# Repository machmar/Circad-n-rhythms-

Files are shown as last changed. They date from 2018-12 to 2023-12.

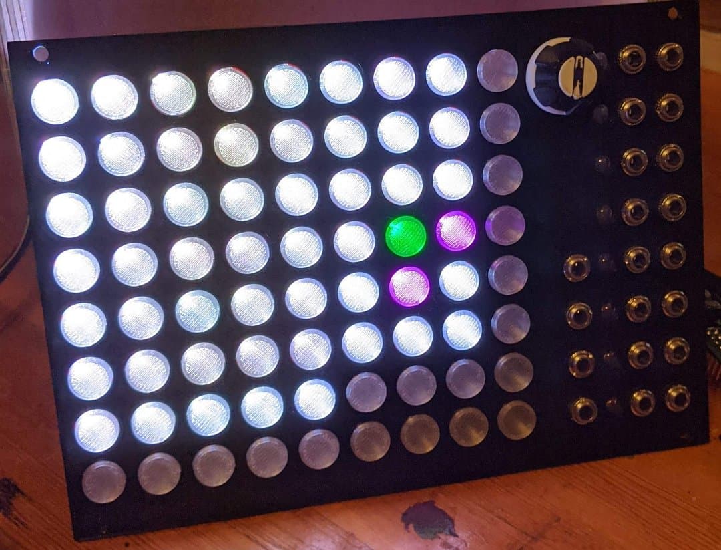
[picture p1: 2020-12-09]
wiki files/flashing/wrong speed.jpg

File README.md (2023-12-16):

# Circad-n-rhythms-

Sadly, this project has stalled and while I have plans to make it much better in the future, there so far is no date for these plans and other stuff is more important right now.    
  
If you are just seeing this module for the first time, let me introduce you to the basic concept of what it is and what it was.  
This is a eurorack module that was originally a clone of *Circadian Rhythms* by *TipTop Audio* but later on I decided to make it my own. I have rewritten the code and redisegined the PCB for it multiple times but never got into a place were the programming would get clean and straight forward. I suspect this is mostly because I coded the whole thing in one file with Arduino IDE. So if any new versions of the code ever come out, it willl be written in Microchip Studio instead.  But the Hardware, other than the noise on powerlines that it makes, is a in a good state with all the stuff nescessary for further development  
  
Anyways, all the mistakes that I am aware are now fixed and the module should be usable and responsive. the DAC is not used so it is not nescessary but if you want to you can have a go at adding the functionality, the protocol should be implemented with functions for intialization, selecting a channel and setting the voltage.

If you want to build it, or even build multiple and sell it to other people, send me an e-mail (marekmach24@gmail.com) and I'll send you the files for 3D printing like the faceplate, buttons and others (I'll also tell you what the serial number should be 🤭🤭). Advantage for doing it this way is that if you face any issues, I can help you out pretty quickly and easilly as you already have a direct line to me.  

More info here:  
Flashing guide [Here on wiki](https://github.com/machmar/Circad-n-rhythms-/wiki/)  
Video overview [on my youtube channel](https://youtu.be/im8Ey7QF54s)

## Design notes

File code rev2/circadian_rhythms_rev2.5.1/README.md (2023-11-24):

It has been a long time and I do not know what I changed in this update other then optimized ram consumption to just 55% instead of 95% which it was previously.  
  
Following is a copy of README.md from 2.5 folder:  
  
This update is different.
The right row of buttons now has a Shift button. The module has a builtin support - just hold any button down for like a seccond and it will tell you.

The list of function of the buttons:

```
[    sequence lenght    ]/[internal / external clock]
[ 64 steps of a channel ]/[-------------------------]
[8 steps of all channels]/[     clock multiplier    ]
[-----------------------]/[-------------------------]
[-----------------------]/[  gate / trigger output  ]
[      play / stop      ]/[-------------------------]
[         Shift         ]/[          Shift          ]
[-----------------------]/[       Save / Load       ]
```

The encoder changes the BPM when you have no menu open, othervise it changes some parameters from the menu.
Also to know what version of software you are on, hold the encoder down while you turn on the module. (the intro animation will play before it displays the version)
More features to come, Marek Mach.

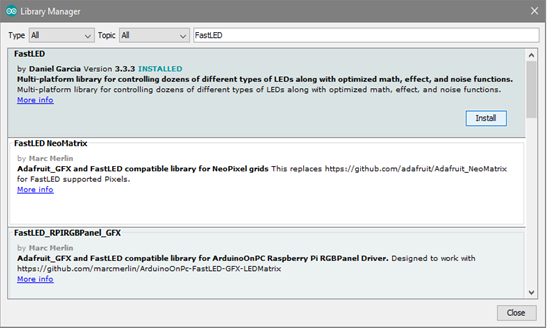
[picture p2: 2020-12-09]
wiki files/flashing/find lib.png

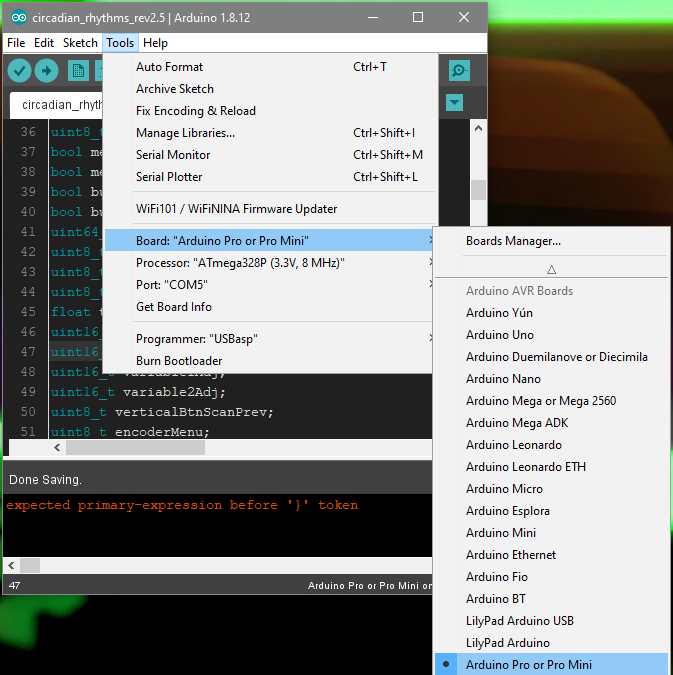
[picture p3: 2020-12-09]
wiki files/flashing/select board.png

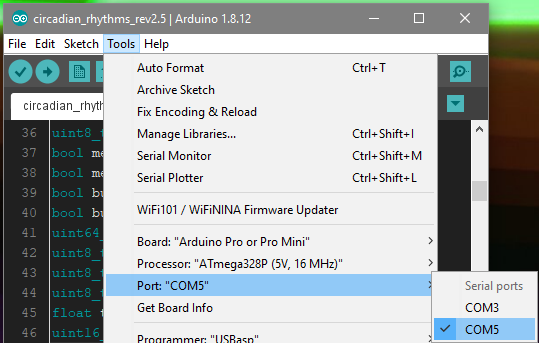
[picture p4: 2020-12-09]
wiki files/flashing/select port.png

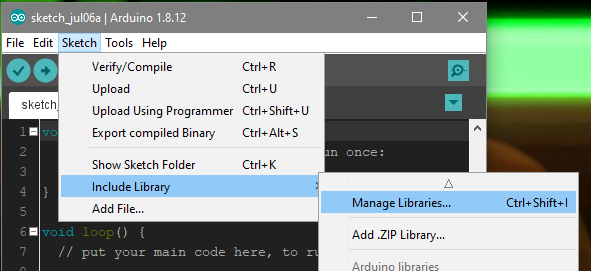
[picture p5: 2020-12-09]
wiki files/flashing/Include lib.png

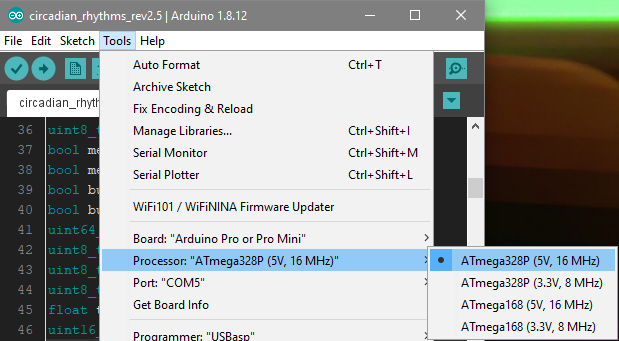
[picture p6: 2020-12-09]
wiki files/flashing/select speed.png

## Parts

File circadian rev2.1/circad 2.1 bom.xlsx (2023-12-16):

Circad rev2.1
Index | Qty | Description | Specs | Value | Package | References
SMT parts, top side
LED1 - LED72 | 72 | SK6812 3535 (chip inside must be facing side with no leads - up on the PCB) |  |  | 3535 | SK6812 3535 RGB LED (https://www.aliexpress.com/item/32623583544.html?spm=a2g0o.cart.0.0.69013c00TGmKdV&mp=1)
S1 - S72 | 72 | MOMENTARY-SWITCH-SMD-6.0X3.5MM | red |  | 6.0x3.5mm | MOMENTARY-SWITCH-SMD-6.0X3.5MM (https://vi.aliexpress.com/item/32914876022.html?spm=a2g0o.cart.0.0.69013c00TGmKdV&mp=1)
C13 - C22 | 10 | capacitor |  | 100n | 603
SMT parts, bottom side
R1, R2, R12 | 3 | resistor |  | 10k | 603
R3 - R11, R27 | 10 | resistor |  | 470 | 603
R13 - R16, R23 | 5 | resistor |  | 1k | 603
C24 | 1 | capacitor |  | 10uF | 603
C1 - C12, C23,C25, C26 | 14 | capacitor |  | 100n | 603
C27, C28 | 2 | capacitor |  | 470n | 603
D1, D2 | 2 | diode |  |  | SOD-123
F1, F2 | 2 | fuse |  | 2A | 1206
RXLED_GREEN | 1 | LED | green |  | 603
TXLED_BLUE | 1 | LED | blue |  | 603
X1 | 1 | USB B 2.0 |  |  |  | 806-KUSBX-SMTBS1NB30 (https://eu.mouser.com/ProductDetail/Kycon/KUSBX-SMT-BS1N-B30?qs=aTQdX%252BfNGTr9wUDDf73bMQ%3D%3D)
VAR_ADJ0, VAR_ADJ1, TEMP_ADJUST, BRIG_ADJUST | 4 | trimmer |  | 10k | 3x3 | Trimpot SMD 3X3 (https://www.aliexpress.com/item/33031044508.html?spm=a2g0o.cart.0.0.5f083c00TJpe2O&mp=1)
IC9 USE ONLY IC9 OR IC10, NOT BOTH! | 1 | zener diode | LM4040B10 | 10V | SOT-23
IC10 USE ONLY IC9 OR IC10, NOT BOTH! | 1 | zener diode | LM4040B05 | 5V | SOT-23
IC4, IC6 | 2 | shift register | 74HC595D |  | SO16
IC2, IC3, IC7 | 2 | multiplexer | 4051D |  | SO16
IC1 | 1 | decade counter | 4017D |  | SO16
IC5 | 1 | multiplexer | 4053D |  | SO16
IC8 | 1 | usb to serial converter | FT232RL |  | SSOP28
U$1 | 1 | temperature sensor | AD22100 |  | SO08
U$2 | 1 | digital analog converter | AD5328 |  | TSSOP16
U$5, U$6 | 2 | pwm voltage regulator | MINI-360 |  |  | Mini-360 Model Step-down Module (https://www.aliexpress.com/item/1631348154.html)
PTH parts, top side
LED73 - LED80 | 8 | 5mm LED | red |  | 5mm | generic 5mm red LED (https://www.aliexpress.com/item/33015212696.html)
CLOCK_IN, CLOCK_OUT, CV_OUT1 - CV_OUT8, TRIG/GATE_OUT1 - TRIG/GATE_OUT8, RESET_IN, RESET_OUT | 20 | Vertical stereo jack connector |  |  |  | PJ366ST (https://www.thonk.co.uk/shop/3-5mm-jacks/)
S73 | 1 | rotary encoder w/ button (D shaft) |  |  |  | 688-EC11E18244A5 (https://eu.mouser.com/ProductDetail/ALPS/EC11E18244A5)
PTH parts, bottom side
U$4 | 1 | 2x5, 2.54mm pitch male header
Arduino pro mini chinese clone | 1 | Arduino pro mini Atmega 328pu | 16MHz 5V |  |  | Arduino pro mini Atmega 328pu 16MHz 5V (https://www.aliexpress.com/item/32824418570.html)
PCB specifications
PCB |  | 173.97mm x 111.43mm ; 2 layers
 | 244

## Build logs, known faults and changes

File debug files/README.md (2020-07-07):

Here are alt firmwares for debugging hardware issues.

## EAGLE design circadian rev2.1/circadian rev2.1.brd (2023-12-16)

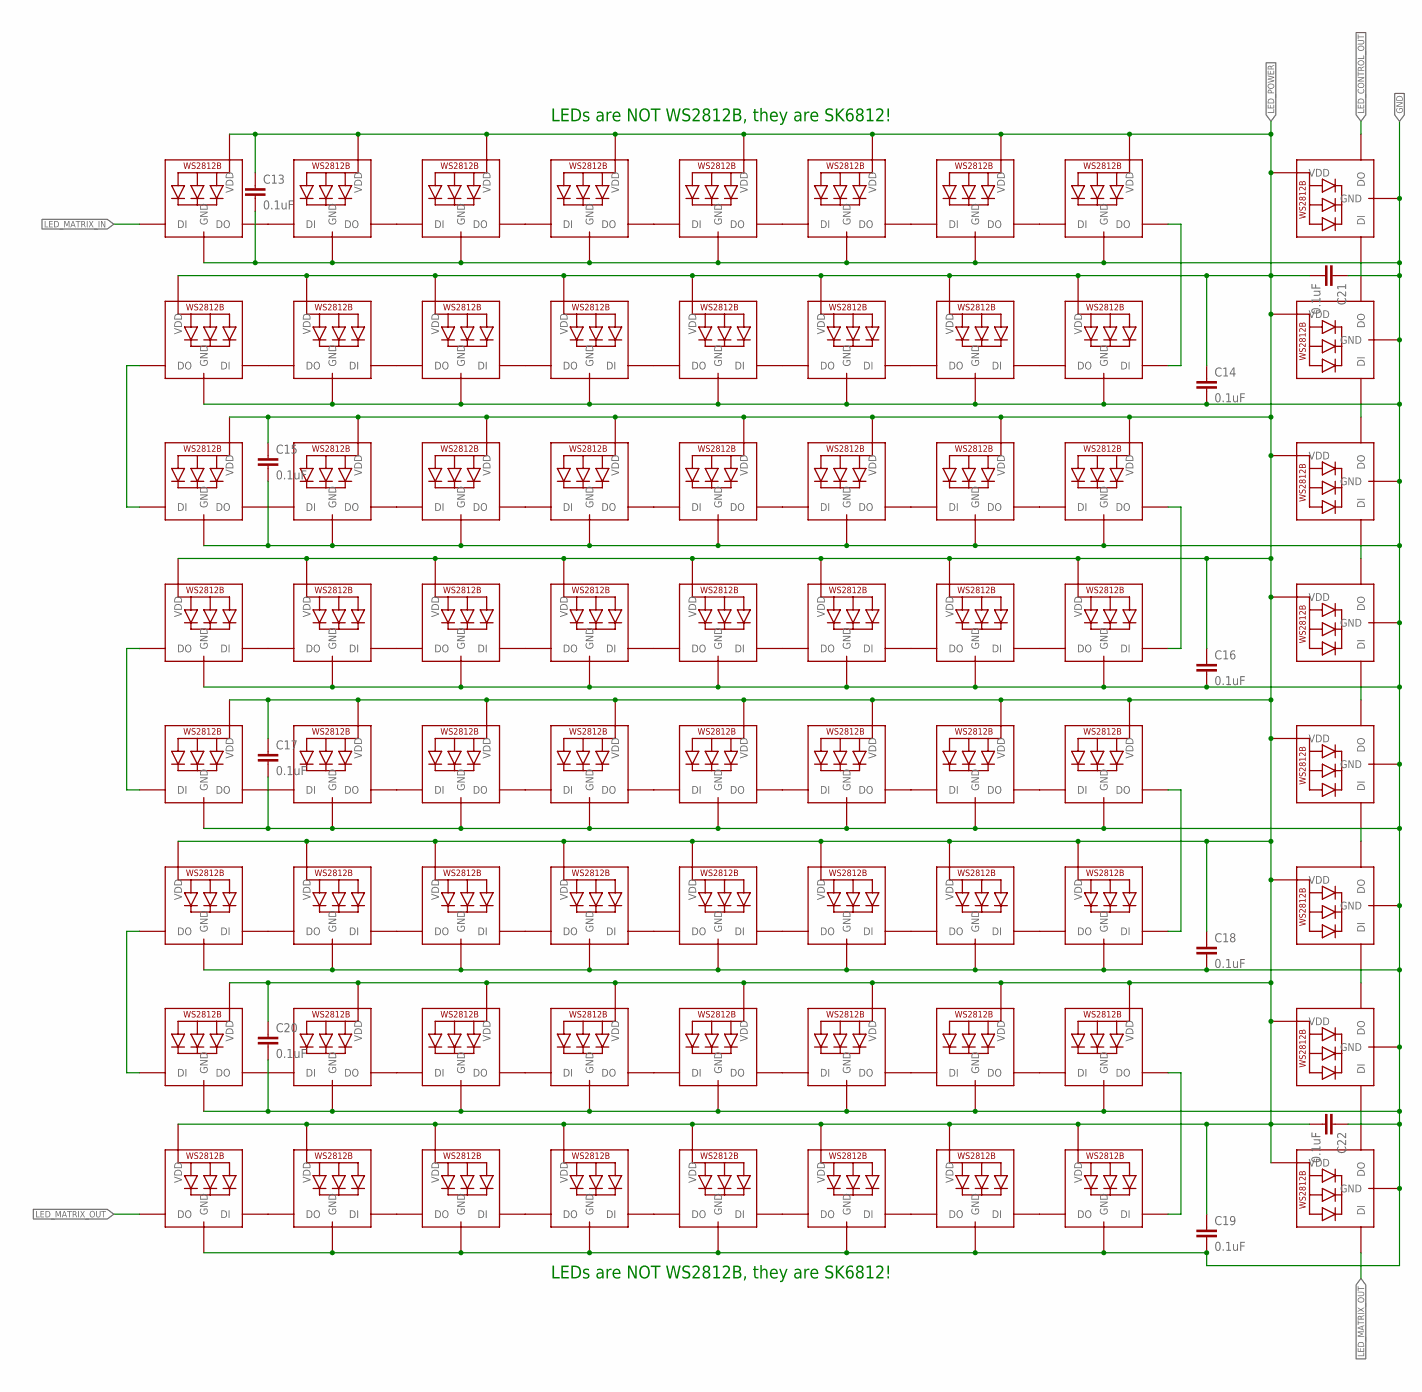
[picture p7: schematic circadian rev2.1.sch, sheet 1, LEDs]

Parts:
C13, C14, C15, C16, C17, C18, C19, C20, C21, C22: 0.1uF; 0603
LED1, LED2, LED3, LED4, LED5, LED6, LED7, LED8, LED9, LED10, LED11, LED12, LED13, LED14, LED15, LED16, LED17, LED18, LED19, LED20, LED21, LED22, LED23, LED24, LED25, LED26, LED27, LED28, LED29, LED30, LED31, LED32, LED33, LED34, LED35, LED36, LED37, LED38, LED39, LED40, LED41, LED42, LED43, LED44, LED45, LED46, LED47, LED48, LED49, LED50, LED51, LED52, LED53, LED54, LED55, LED56, LED57, LED58, LED59, LED60, LED61, LED62, LED63, LED64, LED65, LED66, LED67, LED68, LED69, LED70, LED71, LED72: SK68123535; LED3535

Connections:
GND: C13.2, C14.2, C15.2, C16.2, C17.2, C18.2, C19.2, C20.2, C21.1, C22.1, LED1.4 (GND), LED2.4 (GND), LED3.4 (GND), LED4.4 (GND), LED5.4 (GND), LED6.4 (GND), LED7.4 (GND), LED8.4 (GND), LED9.4 (GND), LED10.4 (GND), LED11.4 (GND), LED12.4 (GND), LED13.4 (GND), LED14.4 (GND), LED15.4 (GND), LED16.4 (GND), LED17.4 (GND), LED18.4 (GND), LED19.4 (GND), LED20.4 (GND), LED21.4 (GND), LED22.4 (GND), LED23.4 (GND), LED24.4 (GND), LED25.4 (GND), LED26.4 (GND), LED27.4 (GND), LED28.4 (GND), LED29.4 (GND), LED30.4 (GND), LED31.4 (GND), LED32.4 (GND), LED33.4 (GND), LED34.4 (GND), LED35.4 (GND), LED36.4 (GND), LED37.4 (GND), LED38.4 (GND), LED39.4 (GND), LED40.4 (GND), LED41.4 (GND), LED42.4 (GND), LED43.4 (GND), LED44.4 (GND), LED45.4 (GND), LED46.4 (GND), LED47.4 (GND), LED48.4 (GND), LED49.4 (GND), LED50.4 (GND), LED51.4 (GND), LED52.4 (GND), LED53.4 (GND), LED54.4 (GND), LED55.4 (GND), LED56.4 (GND), LED57.4 (GND), LED58.4 (GND), LED59.4 (GND), LED60.4 (GND), LED61.4 (GND), LED62.4 (GND), LED63.4 (GND), LED64.4 (GND), LED65.4 (GND), LED66.4 (GND), LED67.4 (GND), LED68.4 (GND), LED69.4 (GND), LED70.4 (GND), LED71.4 (GND), LED72.4 (GND); also elsewhere on the board
LED_CONTROL_OUT: LED65.3 (DO)
LED_MATRIX_IN: LED1.1 (DI); also elsewhere on the board
LED_MATRIX_OUT: LED64.3 (DO), LED72.1 (DI)
LED_POWER: C13.1, C14.1, C15.1, C16.1, C17.1, C18.1, C19.1, C20.1, C21.2, C22.2, LED1.2 (VDD), LED2.2 (VDD), LED3.2 (VDD), LED4.2 (VDD), LED5.2 (VDD), LED6.2 (VDD), LED7.2 (VDD), LED8.2 (VDD), LED9.2 (VDD), LED10.2 (VDD), LED11.2 (VDD), LED12.2 (VDD), LED13.2 (VDD), LED14.2 (VDD), LED15.2 (VDD), LED16.2 (VDD), LED17.2 (VDD), LED18.2 (VDD), LED19.2 (VDD), LED20.2 (VDD), LED21.2 (VDD), LED22.2 (VDD), LED23.2 (VDD), LED24.2 (VDD), LED25.2 (VDD), LED26.2 (VDD), LED27.2 (VDD), LED28.2 (VDD), LED29.2 (VDD), LED30.2 (VDD), LED31.2 (VDD), LED32.2 (VDD), LED33.2 (VDD), LED34.2 (VDD), LED35.2 (VDD), LED36.2 (VDD), LED37.2 (VDD), LED38.2 (VDD), LED39.2 (VDD), LED40.2 (VDD), LED41.2 (VDD), LED42.2 (VDD), LED43.2 (VDD), LED44.2 (VDD), LED45.2 (VDD), LED46.2 (VDD), LED47.2 (VDD), LED48.2 (VDD), LED49.2 (VDD), LED50.2 (VDD), LED51.2 (VDD), LED52.2 (VDD), LED53.2 (VDD), LED54.2 (VDD), LED55.2 (VDD), LED56.2 (VDD), LED57.2 (VDD), LED58.2 (VDD), LED59.2 (VDD), LED60.2 (VDD), LED61.2 (VDD), LED62.2 (VDD), LED63.2 (VDD), LED64.2 (VDD), LED65.2 (VDD), LED66.2 (VDD), LED67.2 (VDD), LED68.2 (VDD), LED69.2 (VDD), LED70.2 (VDD), LED71.2 (VDD), LED72.2 (VDD); also elsewhere on the board
unnamed: LED9.3 (DO), LED10.1 (DI)
unnamed: LED10.3 (DO), LED11.1 (DI)
unnamed: LED11.3 (DO), LED12.1 (DI)
unnamed: LED12.3 (DO), LED13.1 (DI)
unnamed: LED13.3 (DO), LED14.1 (DI)
unnamed: LED14.3 (DO), LED15.1 (DI)
unnamed: LED15.3 (DO), LED16.1 (DI)
unnamed: LED8.3 (DO), LED9.1 (DI)
unnamed: LED17.3 (DO), LED18.1 (DI)
unnamed: LED18.3 (DO), LED19.1 (DI)
unnamed: LED19.3 (DO), LED20.1 (DI)
unnamed: LED20.3 (DO), LED21.1 (DI)
unnamed: LED21.3 (DO), LED22.1 (DI)
unnamed: LED22.3 (DO), LED23.1 (DI)
unnamed: LED23.3 (DO), LED24.1 (DI)
unnamed: LED1.3 (DO), LED2.1 (DI)
unnamed: LED2.3 (DO), LED3.1 (DI)
unnamed: LED3.3 (DO), LED4.1 (DI)
unnamed: LED4.3 (DO), LED5.1 (DI)
unnamed: LED5.3 (DO), LED6.1 (DI)
unnamed: LED6.3 (DO), LED7.1 (DI)
unnamed: LED7.3 (DO), LED8.1 (DI)
unnamed: LED25.3 (DO), LED26.1 (DI)
unnamed: LED26.3 (DO), LED27.1 (DI)
unnamed: LED27.3 (DO), LED28.1 (DI)
unnamed: LED28.3 (DO), LED29.1 (DI)
unnamed: LED29.3 (DO), LED30.1 (DI)
unnamed: LED30.3 (DO), LED31.1 (DI)
unnamed: LED31.3 (DO), LED32.1 (DI)
unnamed: LED24.3 (DO), LED25.1 (DI)
unnamed: LED33.3 (DO), LED34.1 (DI)
unnamed: LED34.3 (DO), LED35.1 (DI)
unnamed: LED35.3 (DO), LED36.1 (DI)
unnamed: LED36.3 (DO), LED37.1 (DI)
unnamed: LED37.3 (DO), LED38.1 (DI)
unnamed: LED38.3 (DO), LED39.1 (DI)
unnamed: LED39.3 (DO), LED40.1 (DI)
unnamed: LED41.3 (DO), LED42.1 (DI)
unnamed: LED42.3 (DO), LED43.1 (DI)
unnamed: LED43.3 (DO), LED44.1 (DI)
unnamed: LED44.3 (DO), LED45.1 (DI)
unnamed: LED45.3 (DO), LED46.1 (DI)
unnamed: LED46.3 (DO), LED47.1 (DI)
unnamed: LED47.3 (DO), LED48.1 (DI)
unnamed: LED40.3 (DO), LED41.1 (DI)
unnamed: LED49.3 (DO), LED50.1 (DI)
unnamed: LED50.3 (DO), LED51.1 (DI)
unnamed: LED51.3 (DO), LED52.1 (DI)
unnamed: LED52.3 (DO), LED53.1 (DI)
unnamed: LED53.3 (DO), LED54.1 (DI)
unnamed: LED54.3 (DO), LED55.1 (DI)
unnamed: LED55.3 (DO), LED56.1 (DI)
unnamed: LED57.3 (DO), LED58.1 (DI)
unnamed: LED58.3 (DO), LED59.1 (DI)
unnamed: LED59.3 (DO), LED60.1 (DI)
unnamed: LED60.3 (DO), LED61.1 (DI)
unnamed: LED61.3 (DO), LED62.1 (DI)
unnamed: LED62.3 (DO), LED63.1 (DI)
unnamed: LED63.3 (DO), LED64.1 (DI)
unnamed: LED56.3 (DO), LED57.1 (DI)
unnamed: LED16.3 (DO), LED17.1 (DI)
unnamed: LED32.3 (DO), LED33.1 (DI)
unnamed: LED48.3 (DO), LED49.1 (DI)
unnamed: LED66.1 (DI), LED67.3 (DO)
unnamed: LED67.1 (DI), LED68.3 (DO)
unnamed: LED68.1 (DI), LED69.3 (DO)
unnamed: LED69.1 (DI), LED70.3 (DO)
unnamed: LED70.1 (DI), LED71.3 (DO)
unnamed: LED71.1 (DI), LED72.3 (DO)
unnamed: LED65.1 (DI), LED66.3 (DO)

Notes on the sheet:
LEDs are NOT WS2812B, they are SK6812!

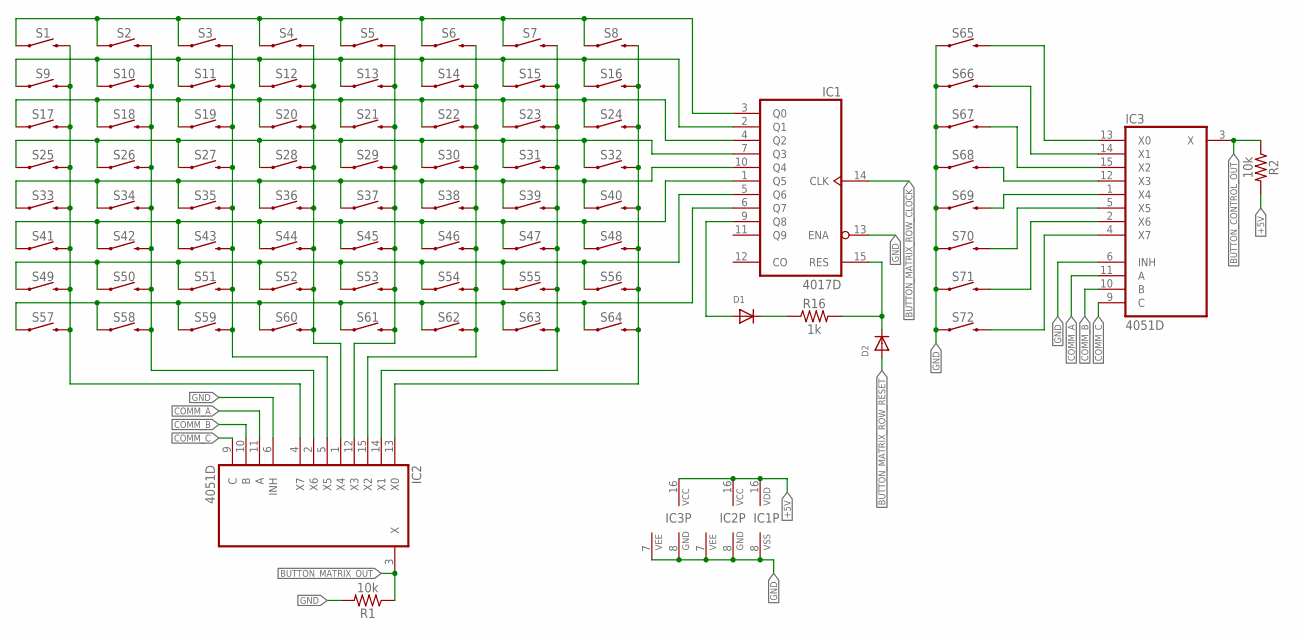
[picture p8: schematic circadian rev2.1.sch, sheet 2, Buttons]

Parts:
D1, D2: DIODESOD-123; SOD-123
IC1: 4017D; SO16
IC2, IC3: 4051D; SO16
R1, R2: 10k; 0603
R16: 1k; 0603
S1, S2, S3, S4, S5, S6, S7, S8, S9, S10, S11, S12, S13, S14, S15, S16, S17, S18, S19, S20, S21, S22, S23, S24, S25, S26, S27, S28, S29, S30, S31, S32, S33, S34, S35, S36, S37, S38, S39, S40, S41, S42, S43, S44, S45, S46, S47, S48, S49, S50, S51, S52, S53, S54, S55, S56, S57, S58, S59, S60, S61, S62, S63, S64, S65, S66, S67, S68, S69, S70, S71, S72: MOMENTARY-SWITCH-SPST-SMD-6.0X3.5MM; TACTILE_SWITCH_SMD_6.0X3.5MM

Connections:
+5V: IC1.16 (VDD), IC2.16 (VCC), IC3.16 (VCC), R2.2; also elsewhere on the board
BUTTON_CONTROL_OUT: IC3.3 (X), R2.1; also elsewhere on the board
BUTTON_MATRIX_COLLUM1: IC2.4 (X7), S1.2, S9.2, S17.2, S25.2, S33.2, S41.2, S49.2, S57.2
BUTTON_MATRIX_COLLUM2: IC2.2 (X6), S2.2, S10.2, S18.2, S26.2, S34.2, S42.2, S50.2, S58.2
BUTTON_MATRIX_COLLUM3: IC2.5 (X5), S3.2, S11.2, S19.2, S27.2, S35.2, S43.2, S51.2, S59.2
BUTTON_MATRIX_COLLUM4: IC2.1 (X4), S4.2, S12.2, S20.2, S28.2, S36.2, S44.2, S52.2, S60.2
BUTTON_MATRIX_COLLUM5: IC2.12 (X3), S5.2, S13.2, S21.2, S29.2, S37.2, S45.2, S53.2, S61.2
BUTTON_MATRIX_COLLUM6: IC2.15 (X2), S6.2, S14.2, S22.2, S30.2, S38.2, S46.2, S54.2, S62.2
BUTTON_MATRIX_COLLUM7: IC2.14 (X1), S7.2, S15.2, S23.2, S31.2, S39.2, S47.2, S55.2, S63.2
BUTTON_MATRIX_COLLUM8: IC2.13 (X0), S8.2, S16.2, S24.2, S32.2, S40.2, S48.2, S56.2, S64.2
BUTTON_MATRIX_OUT: IC2.3 (X), R1.1; also elsewhere on the board
BUTTON_MATRIX_ROW1: IC1.3 (Q0), S1.1, S2.1, S3.1, S4.1, S5.1, S6.1, S7.1, S8.1
BUTTON_MATRIX_ROW2: IC1.2 (Q1), S9.1, S10.1, S11.1, S12.1, S13.1, S14.1, S15.1, S16.1
BUTTON_MATRIX_ROW3: IC1.4 (Q2), S17.1, S18.1, S19.1, S20.1, S21.1, S22.1, S23.1, S24.1
BUTTON_MATRIX_ROW4: IC1.7 (Q3), S25.1, S26.1, S27.1, S28.1, S29.1, S30.1, S31.1, S32.1
BUTTON_MATRIX_ROW5: IC1.10 (Q4), S33.1, S34.1, S35.1, S36.1, S37.1, S38.1, S39.1, S40.1
BUTTON_MATRIX_ROW6: IC1.1 (Q5), S41.1, S42.1, S43.1, S44.1, S45.1, S46.1, S47.1, S48.1
BUTTON_MATRIX_ROW7: IC1.5 (Q6), S49.1, S50.1, S51.1, S52.1, S53.1, S54.1, S55.1, S56.1
BUTTON_MATRIX_ROW8: IC1.6 (Q7), S57.1, S58.1, S59.1, S60.1, S61.1, S62.1, S63.1, S64.1
BUTTON_MATRIX_ROW_CLOCK: IC1.14 (CLK); also elsewhere on the board
BUTTON_MATRIX_ROW_RESET: D2.A; also elsewhere on the board
COMM_A: IC2.11 (A), IC3.11 (A); also elsewhere on the board
COMM_B: IC2.10 (B), IC3.10 (B); also elsewhere on the board
COMM_C: IC2.9 (C), IC3.9 (C); also elsewhere on the board
GND: IC1.8 (VSS), IC1.13 (ENA), IC2.6 (INH), IC2.7 (VEE), IC2.8 (GND), IC3.6 (INH), IC3.7 (VEE), IC3.8 (GND), R1.2, S65.1, S66.1, S67.1, S68.1, S69.1, S70.1, S71.1, S72.1; also elsewhere on the board
unnamed: IC3.12 (X3), S68.2
unnamed: IC3.1 (X4), S69.2
unnamed: IC3.5 (X5), S70.2
unnamed: IC3.15 (X2), S67.2
unnamed: IC3.14 (X1), S66.2
unnamed: IC3.13 (X0), S65.2
unnamed: IC3.2 (X6), S71.2
unnamed: IC3.4 (X7), S72.2
unnamed: D1.C, R16.1
unnamed: D1.A, IC1.9 (Q8)
unnamed: D2.C, IC1.15 (RES), R16.2

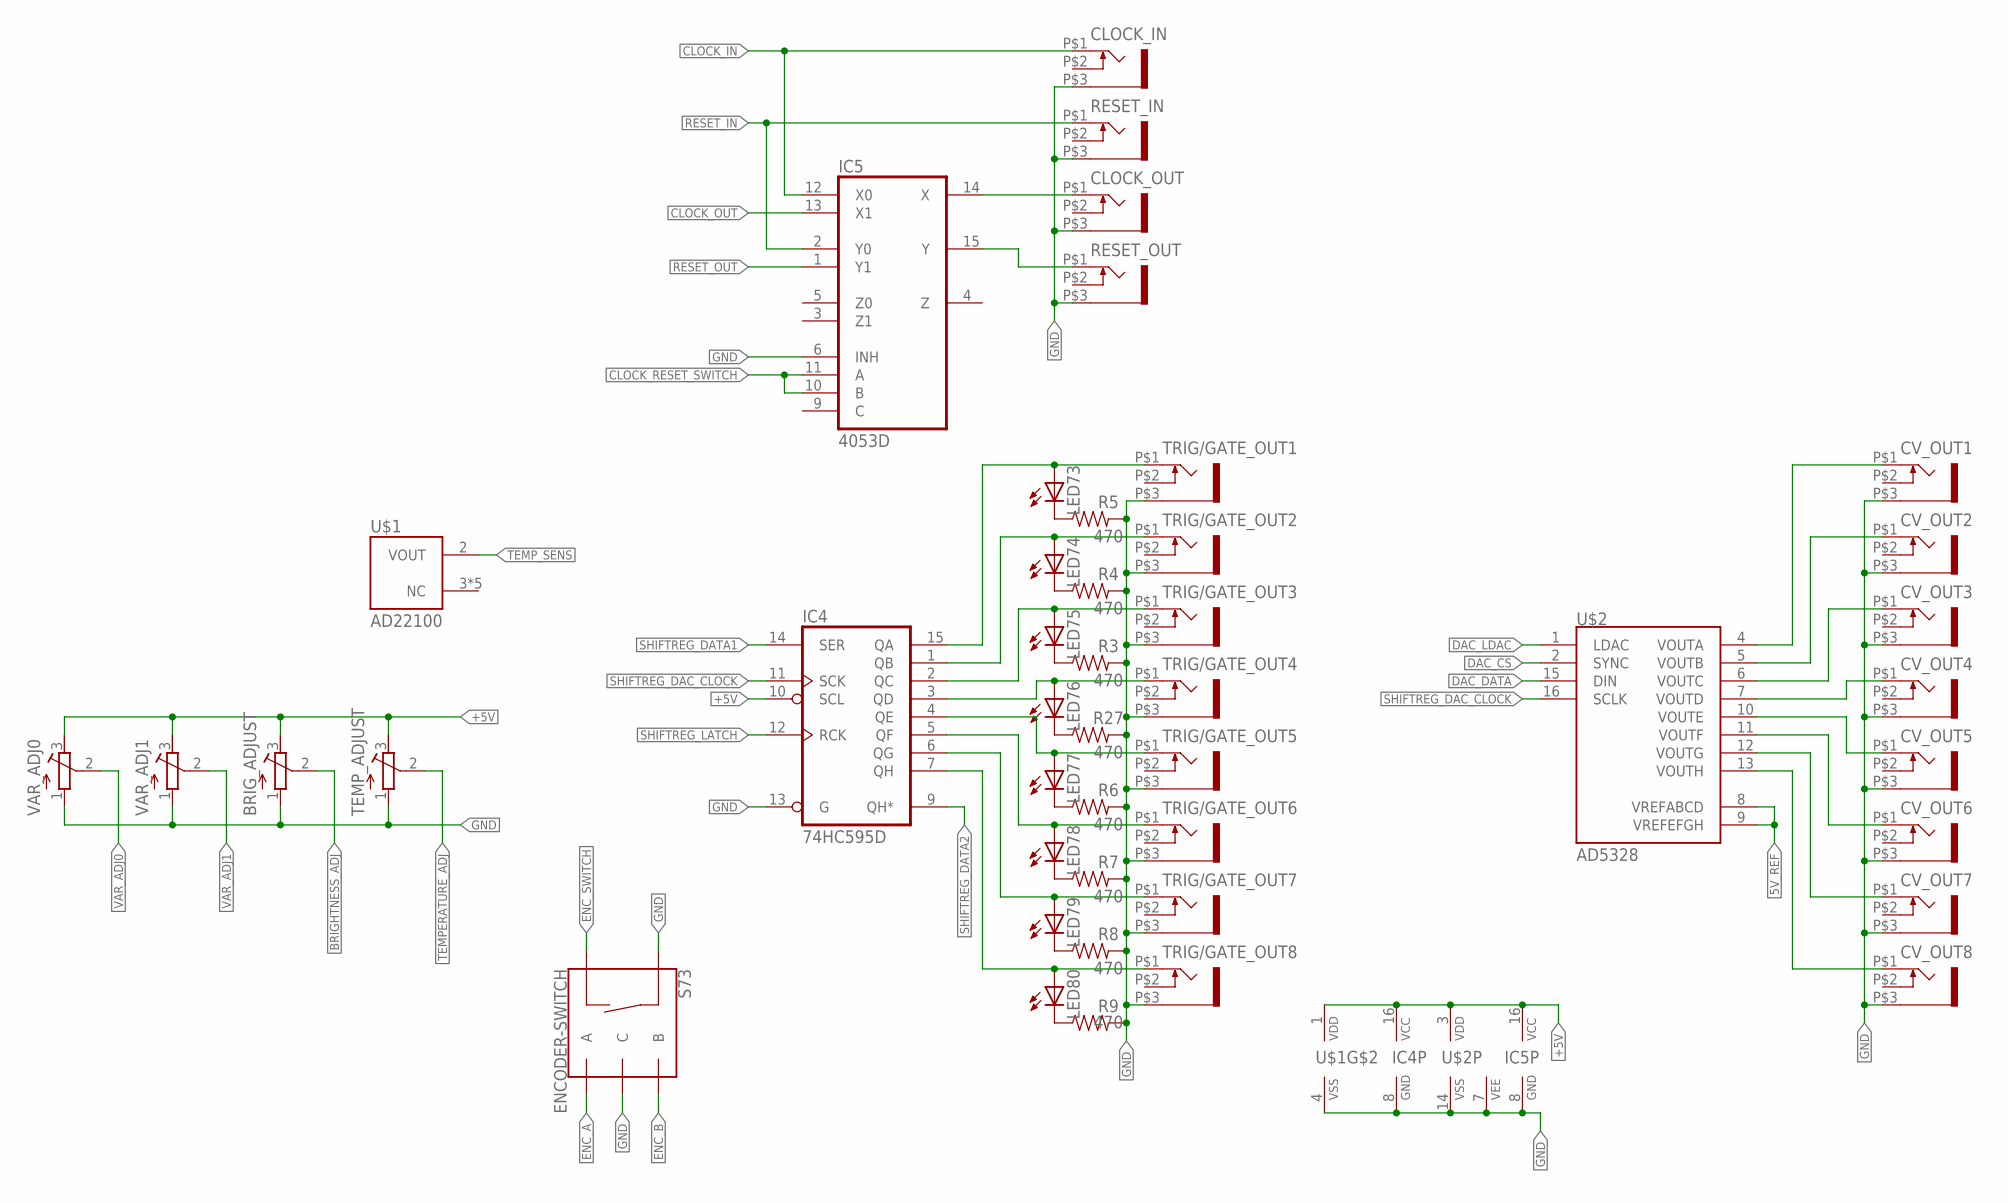
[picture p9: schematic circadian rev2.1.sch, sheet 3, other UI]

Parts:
BRIG_ADJUST: R-TRIMM4G/J; RTRIM4G/J
CLOCK_IN: WQP-PJ301M-12_JACK
CLOCK_OUT: WQP-PJ301M-12_JACK
CV_OUT1, CV_OUT2, CV_OUT3, CV_OUT4, CV_OUT5, CV_OUT6, CV_OUT7, CV_OUT8: WQP-PJ301M-12_JACK
IC4: 74HC595D; SO16
IC5: 4053D; SO16
LED73, LED74, LED75, LED76, LED77, LED78, LED79, LED80: LED5MM
R3, R4, R5, R6, R7, R8, R9, R27: 470; 0603
RESET_IN: WQP-PJ301M-12_JACK
RESET_OUT: WQP-PJ301M-12_JACK
S73: ENCODER-SWITCH; ROTARY_ENC_PLAIN
TEMP_ADJUST: R-TRIMM4G/J; RTRIM4G/J
TRIG/GATE_OUT1, TRIG/GATE_OUT2, TRIG/GATE_OUT3, TRIG/GATE_OUT4, TRIG/GATE_OUT5, TRIG/GATE_OUT6, TRIG/GATE_OUT7, TRIG/GATE_OUT8: WQP-PJ301M-12_JACK
U$1: AD22100; SO08
U$2: AD5328; TSSOP-16
VAR_ADJ0, VAR_ADJ1: R-TRIMM4G/J; RTRIM4G/J

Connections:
5V_REF: U$2.8 (VREFABCD), U$2.9 (VREFEFGH); also elsewhere on the board
+5V: BRIG_ADJUST.3 (E), IC4.10 (SCL), IC4.16 (VCC), IC5.16 (VCC), TEMP_ADJUST.3 (E), U$1.1 (VDD), U$2.3 (VDD), VAR_ADJ0.3 (E), VAR_ADJ1.3 (E); also elsewhere on the board
BRIGHTNESS_ADJ: BRIG_ADJUST.2 (S); also elsewhere on the board
CLOCK_IN: CLOCK_IN.P$1 (2), IC5.12 (X0); also elsewhere on the board
CLOCK_OUT: IC5.13 (X1); also elsewhere on the board
CLOCK_RESET_SWITCH: IC5.10 (B), IC5.11 (A); also elsewhere on the board
DAC_CS: U$2.2 (SYNC); also elsewhere on the board
DAC_DATA: U$2.15 (DIN); also elsewhere on the board
DAC_LDAC: U$2.1 (LDAC); also elsewhere on the board
ENC_A: S73.A; also elsewhere on the board
ENC_B: S73.B; also elsewhere on the board
ENC_SWITCH: S73.SW-; also elsewhere on the board
GND: BRIG_ADJUST.1 (A), CLOCK_IN.P$3 (1), CLOCK_OUT.P$3 (1), CV_OUT1.P$3 (1), CV_OUT2.P$3 (1), CV_OUT3.P$3 (1), CV_OUT4.P$3 (1), CV_OUT5.P$3 (1), CV_OUT6.P$3 (1), CV_OUT7.P$3 (1), CV_OUT8.P$3 (1), IC4.8 (GND), IC4.13 (G), IC5.6 (INH), IC5.7 (VEE), IC5.8 (GND), R3.2, R4.2, R5.2, R6.2, R7.2, R8.2, R9.2, R27.2, RESET_IN.P$3 (1), RESET_OUT.P$3 (1), S73.C, S73.SW+, TEMP_ADJUST.1 (A), TRIG/GATE_OUT1.P$3 (1), TRIG/GATE_OUT2.P$3 (1), TRIG/GATE_OUT3.P$3 (1), TRIG/GATE_OUT4.P$3 (1), TRIG/GATE_OUT5.P$3 (1), TRIG/GATE_OUT6.P$3 (1), TRIG/GATE_OUT7.P$3 (1), TRIG/GATE_OUT8.P$3 (1), U$1.4 (VSS), U$2.14 (VSS), VAR_ADJ0.1 (A), VAR_ADJ1.1 (A); also elsewhere on the board
unnamed: IC4.4 (QE), LED77.A, TRIG/GATE_OUT5.P$1 (2)
unnamed: IC4.3 (QD), LED76.A, TRIG/GATE_OUT4.P$1 (2)
unnamed: IC4.5 (QF), LED78.A, TRIG/GATE_OUT6.P$1 (2)
unnamed: IC4.6 (QG), LED79.A, TRIG/GATE_OUT7.P$1 (2)
unnamed: IC4.7 (QH), LED80.A, TRIG/GATE_OUT8.P$1 (2)
unnamed: IC4.2 (QC), LED75.A, TRIG/GATE_OUT3.P$1 (2)
unnamed: IC4.1 (QB), LED74.A, TRIG/GATE_OUT2.P$1 (2)
unnamed: IC4.15 (QA), LED73.A, TRIG/GATE_OUT1.P$1 (2)
unnamed: CV_OUT4.P$1 (2), U$2.7 (VOUTD)
unnamed: CV_OUT5.P$1 (2), U$2.10 (VOUTE)
unnamed: CV_OUT6.P$1 (2), U$2.11 (VOUTF)
unnamed: CV_OUT7.P$1 (2), U$2.12 (VOUTG)
unnamed: CV_OUT8.P$1 (2), U$2.13 (VOUTH)
unnamed: CV_OUT3.P$1 (2), U$2.6 (VOUTC)
unnamed: CV_OUT2.P$1 (2), U$2.5 (VOUTB)
unnamed: CV_OUT1.P$1 (2), U$2.4 (VOUTA)
unnamed: CLOCK_OUT.P$1 (2), IC5.14 (X)
unnamed: IC5.15 (Y), RESET_OUT.P$1 (2)
unnamed: LED76.K (C), R27.1
unnamed: LED75.K (C), R3.1
unnamed: LED74.K (C), R4.1
unnamed: LED73.K (C), R5.1
unnamed: LED77.K (C), R6.1
unnamed: LED78.K (C), R7.1
unnamed: LED79.K (C), R8.1
unnamed: LED80.K (C), R9.1
RESET_IN: IC5.2 (Y0), RESET_IN.P$1 (2); also elsewhere on the board
RESET_OUT: IC5.1 (Y1); also elsewhere on the board
SHIFTREG_DAC_CLOCK: IC4.11 (SCK), U$2.16 (SCLK); also elsewhere on the board
SHIFTREG_DATA1: IC4.14 (SER); also elsewhere on the board
SHIFTREG_DATA2: IC4.9 (QH*)
SHIFTREG_LATCH: IC4.12 (RCK); also elsewhere on the board
TEMPERATURE_ADJ: TEMP_ADJUST.2 (S); also elsewhere on the board
TEMP_SENS: U$1.2 (VOUT); also elsewhere on the board
VAR_ADJ0: VAR_ADJ0.2 (S); also elsewhere on the board
VAR_ADJ1: VAR_ADJ1.2 (S); also elsewhere on the board

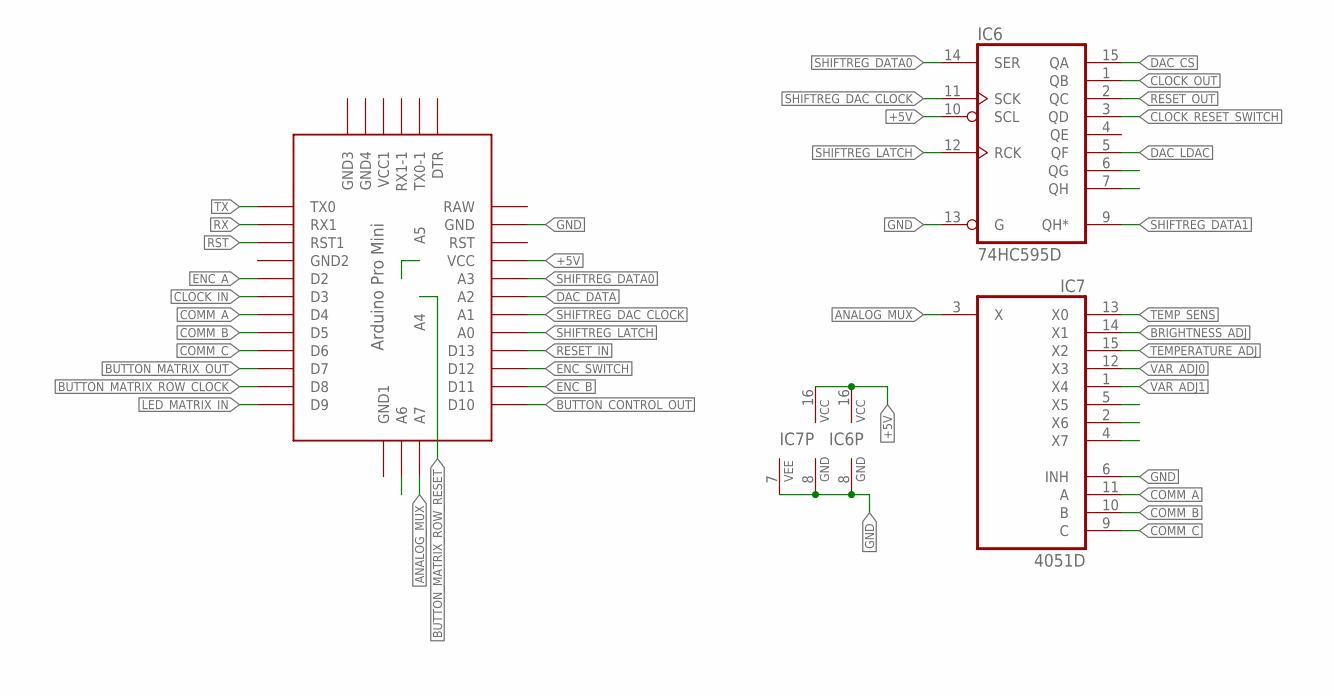
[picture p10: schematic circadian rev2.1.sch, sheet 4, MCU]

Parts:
IC6: 74HC595D; SO16
IC7: 4051D; SO16
U$3: ABK-PRO-MINI

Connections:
+5V: IC6.10 (SCL), IC6.16 (VCC), IC7.16 (VCC), U$3.VCC; also elsewhere on the board
ANALOG_MUX: IC7.3 (X), U$3.A7
BRIGHTNESS_ADJ: IC7.14 (X1); also elsewhere on the board
BUTTON_CONTROL_OUT: U$3.D10; also elsewhere on the board
BUTTON_MATRIX_OUT: U$3.D7; also elsewhere on the board
BUTTON_MATRIX_ROW_CLOCK: U$3.D8; also elsewhere on the board
BUTTON_MATRIX_ROW_RESET: U$3.A4; also elsewhere on the board
CLOCK_IN: U$3.D3; also elsewhere on the board
CLOCK_OUT: IC6.1 (QB); also elsewhere on the board
CLOCK_RESET_SWITCH: IC6.3 (QD); also elsewhere on the board
COMM_A: IC7.11 (A), U$3.D4; also elsewhere on the board
COMM_B: IC7.10 (B), U$3.D5; also elsewhere on the board
COMM_C: IC7.9 (C), U$3.D6; also elsewhere on the board
DAC_CS: IC6.15 (QA); also elsewhere on the board
DAC_DATA: U$3.A2; also elsewhere on the board
DAC_LDAC: IC6.5 (QF); also elsewhere on the board
ENC_A: U$3.D2; also elsewhere on the board
ENC_B: U$3.D11; also elsewhere on the board
ENC_SWITCH: U$3.D12; also elsewhere on the board
GND: IC6.8 (GND), IC6.13 (G), IC7.6 (INH), IC7.7 (VEE), IC7.8 (GND), U$3.GND; also elsewhere on the board
LED_MATRIX_IN: U$3.D9; also elsewhere on the board
RESET_IN: U$3.D13; also elsewhere on the board
RESET_OUT: IC6.2 (QC); also elsewhere on the board
RST: U$3.RST1; also elsewhere on the board
RX: U$3.RX1; also elsewhere on the board
SHIFTREG_DAC_CLOCK: IC6.11 (SCK), U$3.A1; also elsewhere on the board
SHIFTREG_DATA0: IC6.14 (SER), U$3.A3
SHIFTREG_DATA1: IC6.9 (QH*); also elsewhere on the board
SHIFTREG_LATCH: IC6.12 (RCK), U$3.A0; also elsewhere on the board
TEMPERATURE_ADJ: IC7.15 (X2); also elsewhere on the board
TEMP_SENS: IC7.13 (X0); also elsewhere on the board
TX: U$3.TX0; also elsewhere on the board
VAR_ADJ0: IC7.12 (X3); also elsewhere on the board
VAR_ADJ1: IC7.1 (X4); also elsewhere on the board

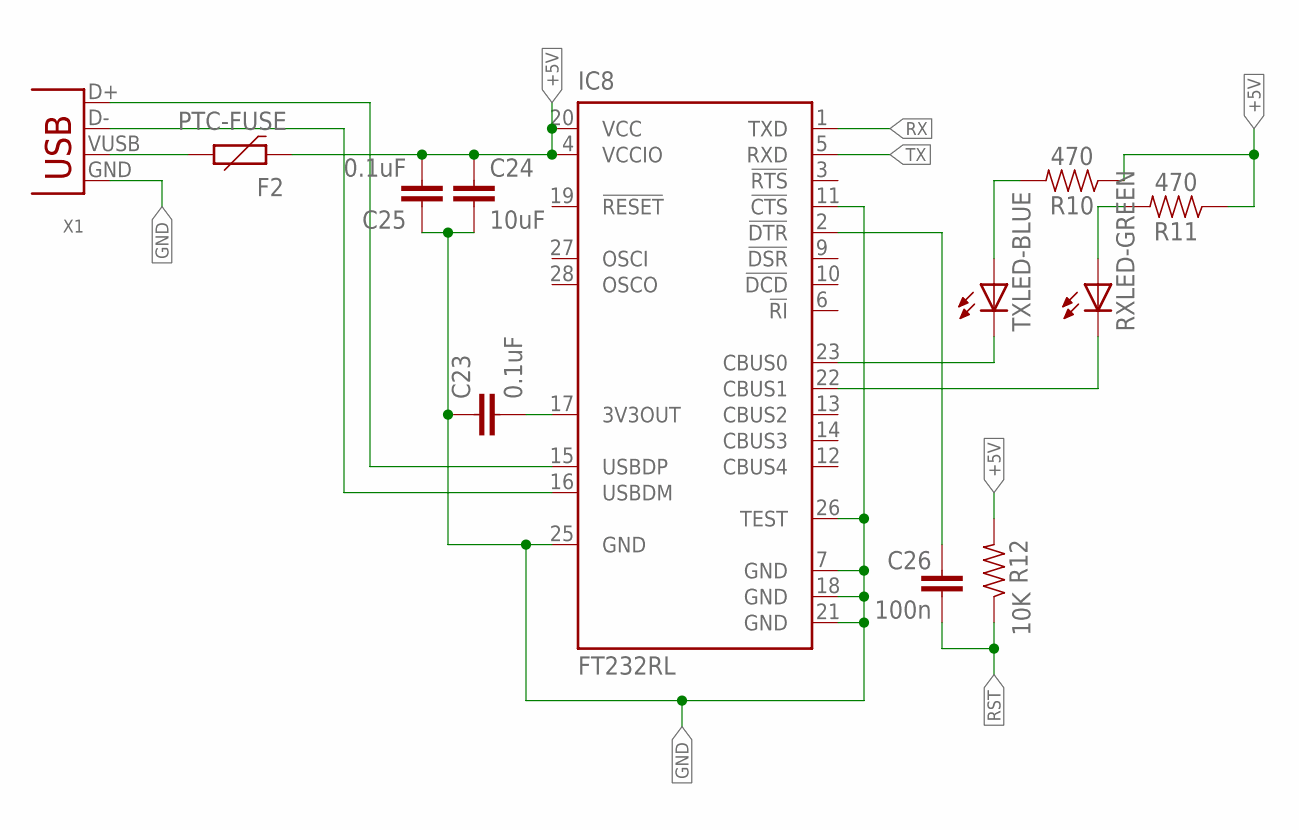
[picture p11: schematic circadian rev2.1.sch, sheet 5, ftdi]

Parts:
C23, C25: 0.1uF; 0603
C24: 10uF; 0603
C26: 100n; 0603-CAP
F2: PTC-FUSE; 1206
IC8: FT232RL; SSOP28
R10, R11: 470; 0603
R12: 10K; 0603-RES
RXLED-GREEN: LEDCHIP-LED0603; CHIP-LED0603
TXLED-BLUE: LEDCHIP-LED0603; CHIP-LED0603
X1: USB-B-S; USB-B-SMT

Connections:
+5V: C24.1, C25.2, F2.1, IC8.4 (VCCIO), IC8.20 (VCC), R10.1, R11.1, R12.2; also elsewhere on the board
DTR: C26.2, IC8.2 (!DTR)
GND: C23.1, C24.2, C25.1, IC8.7 (GND), IC8.11 (!CTS), IC8.18 (GND), IC8.21 (GND), IC8.25 (GND), IC8.26 (TEST), X1.GND; also elsewhere on the board
unnamed: R10.2, TXLED-BLUE.A
unnamed: R11.2, RXLED-GREEN.A
unnamed: IC8.23 (CBUS0), TXLED-BLUE.C
unnamed: IC8.22 (CBUS1), RXLED-GREEN.C
unnamed: F2.2, X1.VUSB (VBUS)
unnamed: IC8.15 (USBDP), X1.D+
unnamed: IC8.16 (USBDM), X1.D-
unnamed: C23.2, IC8.17 (3V3OUT)
RST: C26.1, R12.1; also elsewhere on the board
RX: IC8.1 (TXD); also elsewhere on the board
TX: IC8.5 (RXD); also elsewhere on the board

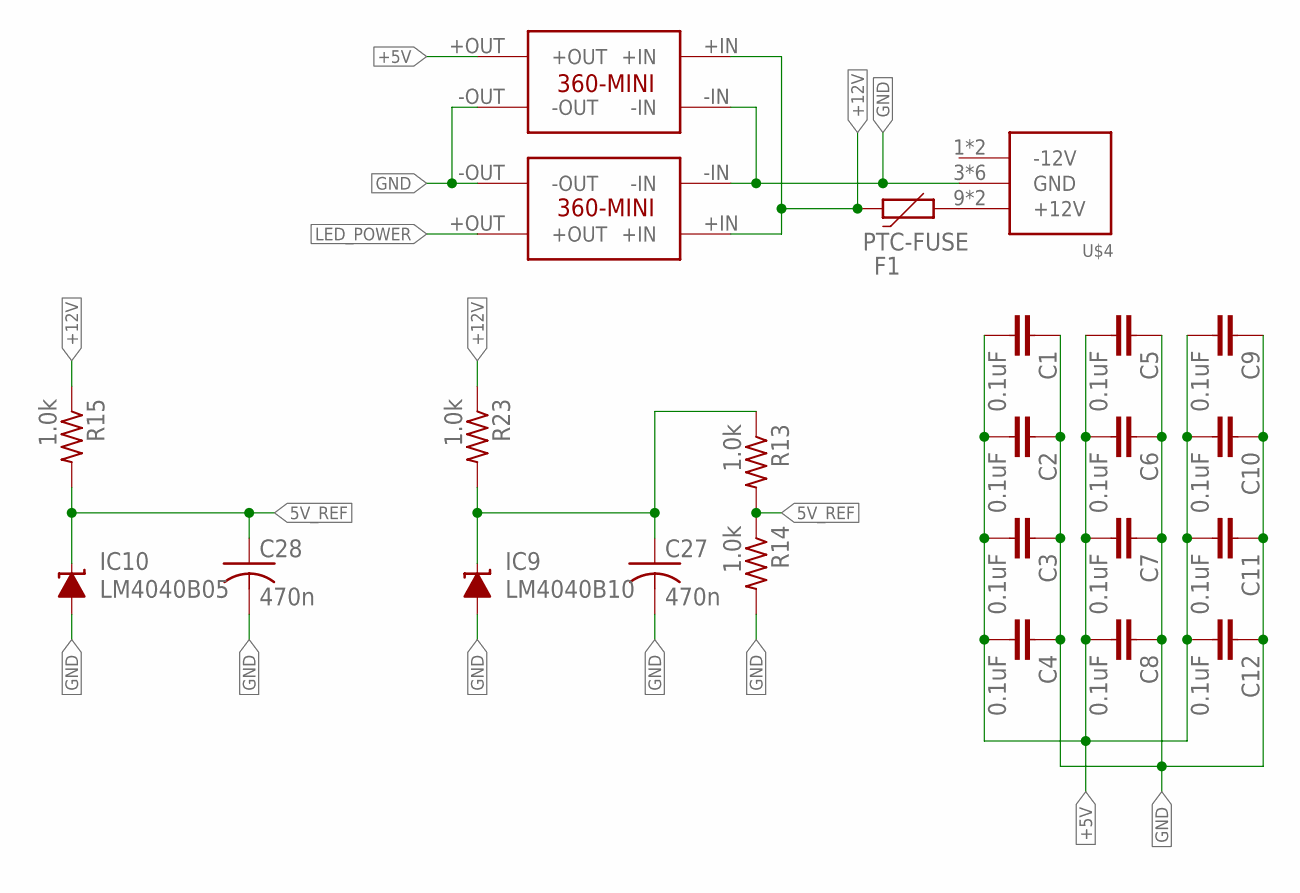
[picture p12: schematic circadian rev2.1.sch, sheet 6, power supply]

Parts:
C1, C2, C3, C4, C5, C6, C7, C8, C9, C10, C11, C12: 0.1uF; 0603
C27, C28: 470n; C0603
F1: PTC-FUSE; 1206
IC9: LM4040B10; DBZ_R-PDSO-G3
IC10: LM4040B05; DBZ_R-PDSO-G3
R13, R14, R15, R23: 1.0k; R0603
U$4: POWER_SIMPLE10; POWER_10
U$5, U$6: MINI-360SMD

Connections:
5V_REF: C28.1, IC10.1 (C), R13.2, R14.1, R15.2; also elsewhere on the board
+5V: C1.2, C2.2, C3.2, C4.2, C5.2, C6.2, C7.2, C8.2, C9.2, C10.2, C11.2, C12.2, U$6.+OUT; also elsewhere on the board
+12V: F1.1, R15.1, R23.1, U$5.+IN, U$6.+IN
AREF: C27.1, IC9.1 (C), R13.1, R23.2
GND: C1.1, C2.1, C3.1, C4.1, C5.1, C6.1, C7.1, C8.1, C9.1, C10.1, C11.1, C12.1, C27.2, C28.2, IC9.2 (A), IC10.2 (A), R14.2, U$4.3 (GND), U$4.4 (GND), U$4.5 (GND), U$4.6 (GND), U$4.7 (GND), U$4.8 (GND), U$5.-IN, U$5.-OUT, U$6.-IN, U$6.-OUT; also elsewhere on the board
LED_POWER: U$5.+OUT; also elsewhere on the board
unnamed: F1.2, U$4.9 (+12V), U$4.10 (+12V)

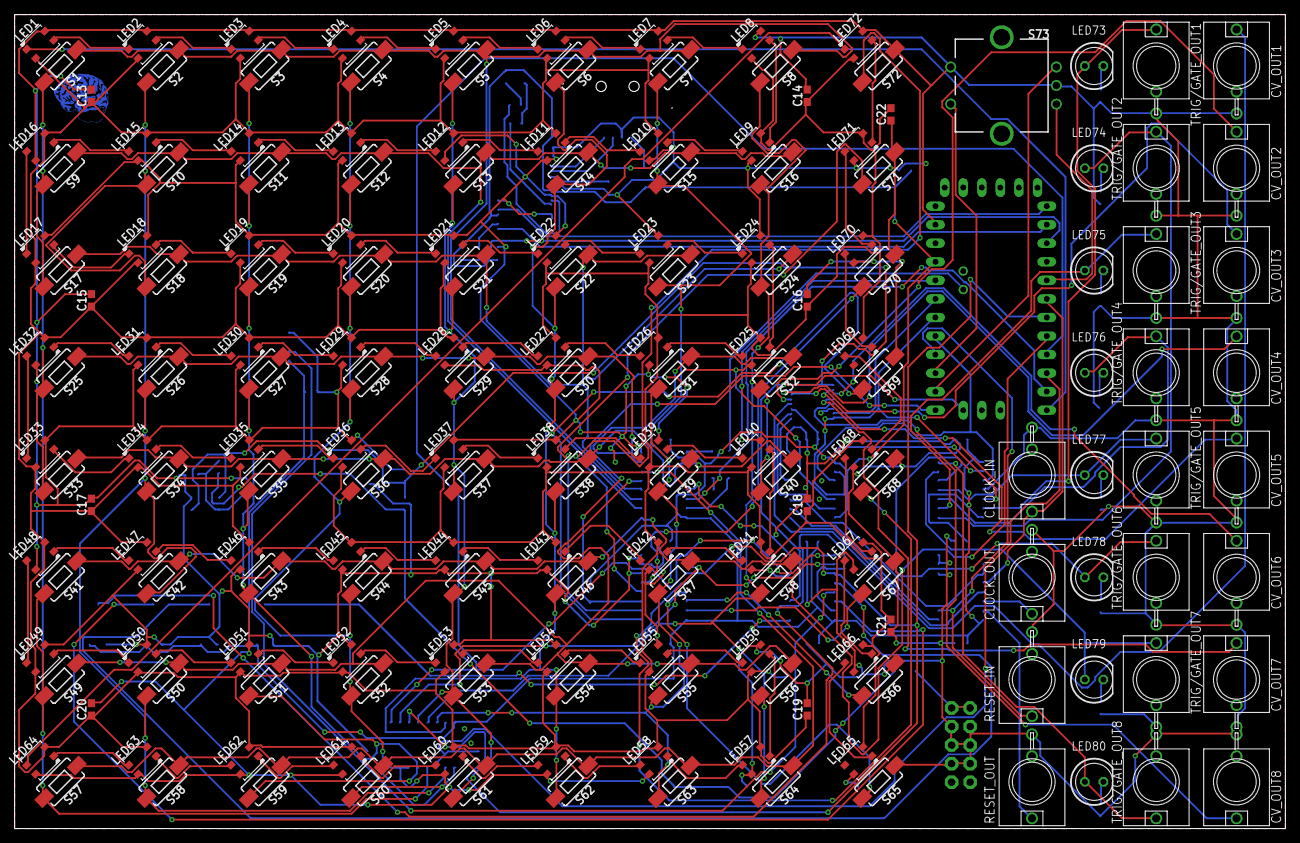
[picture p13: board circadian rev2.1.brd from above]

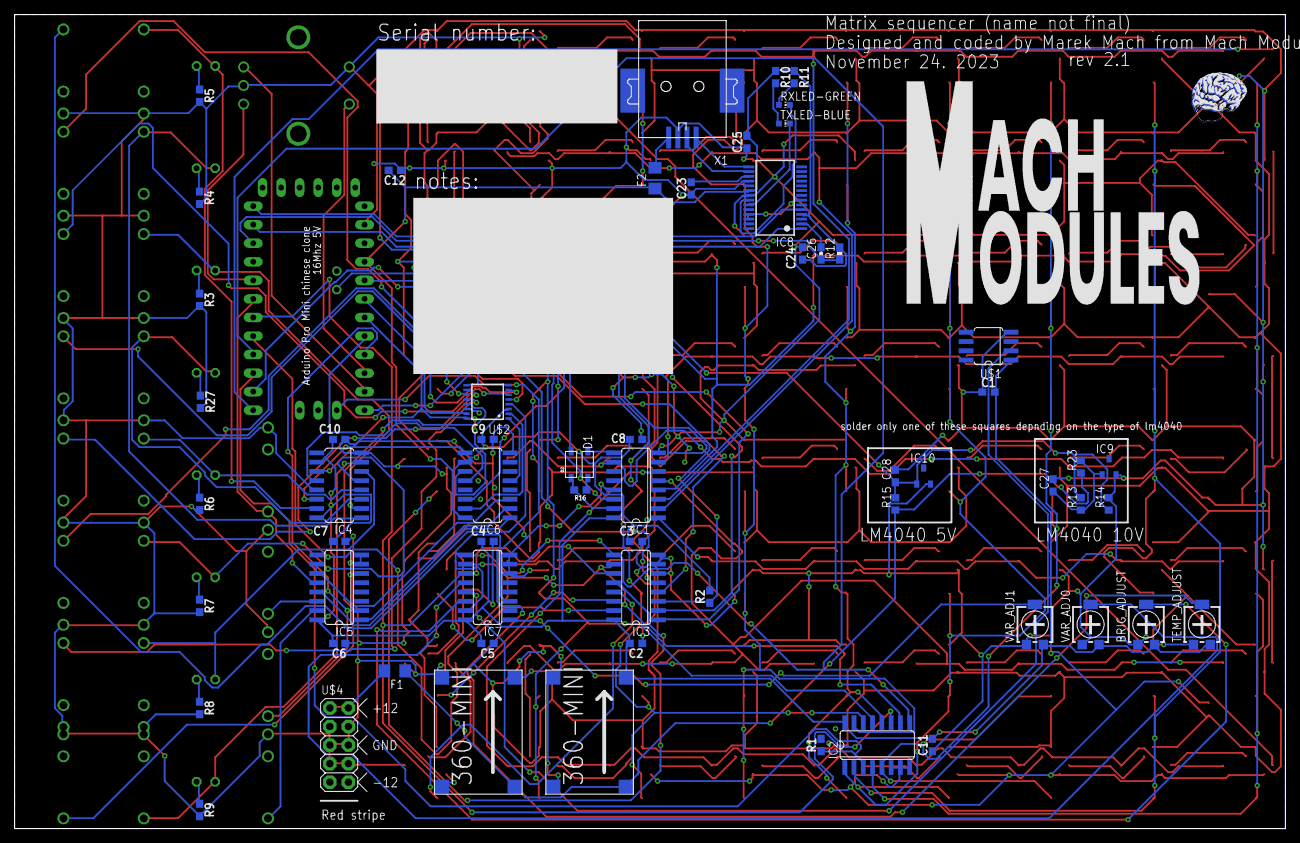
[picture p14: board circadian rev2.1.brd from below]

Board: 2 copper layers, 174.0 x 111.4 mm, 246 parts (63 on the bottom side), 172 nets.

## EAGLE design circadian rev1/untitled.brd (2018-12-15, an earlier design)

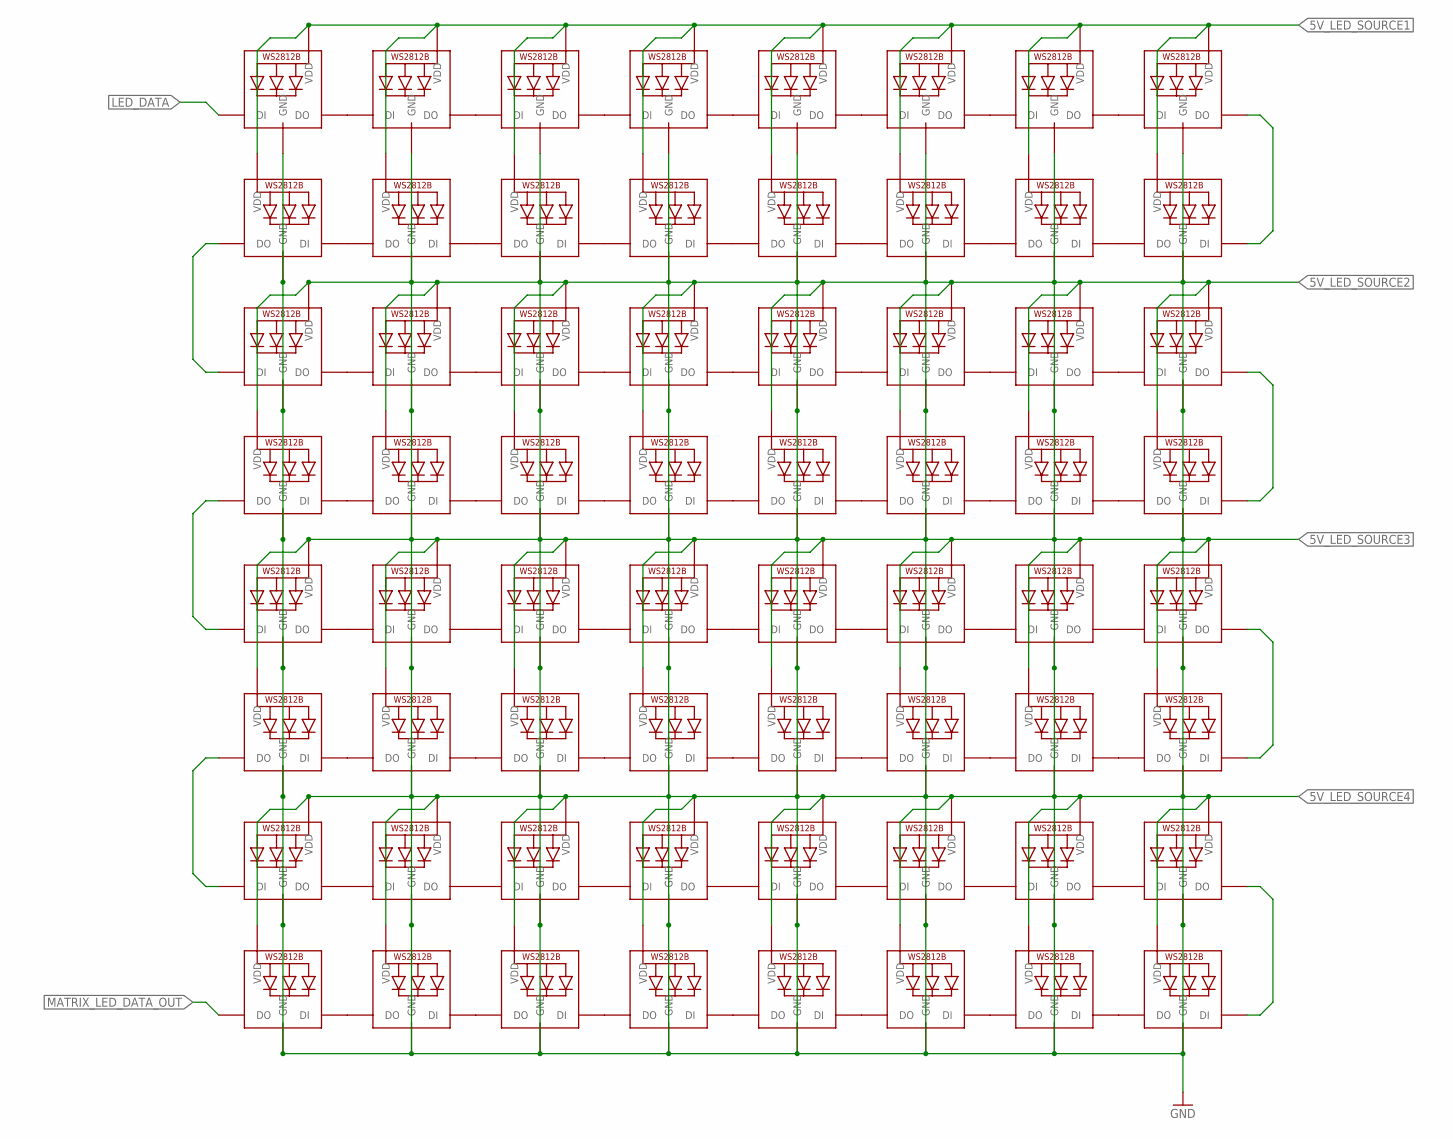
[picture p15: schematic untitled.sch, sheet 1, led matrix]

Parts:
LED1, LED2, LED3, LED4, LED5, LED6, LED7, LED8, LED9, LED10, LED11, LED12, LED13, LED14, LED15, LED16, LED17, LED18, LED19, LED20, LED21, LED22, LED23, LED24, LED25, LED26, LED27, LED28, LED29, LED30, LED31, LED32, LED33, LED34, LED35, LED36, LED37, LED38, LED39, LED40, LED41, LED42, LED43, LED44, LED45, LED46, LED47, LED48, LED49, LED50, LED51, LED52, LED53, LED54, LED55, LED56, LED57, LED58, LED59, LED60, LED61, LED62, LED63, LED64: WS2812B3535; LED3535

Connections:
5V_LED_SOURCE1: LED1.2 (VDD), LED2.2 (VDD), LED3.2 (VDD), LED4.2 (VDD), LED5.2 (VDD), LED6.2 (VDD), LED7.2 (VDD), LED8.2 (VDD), LED9.2 (VDD), LED10.2 (VDD), LED11.2 (VDD), LED12.2 (VDD), LED13.2 (VDD), LED14.2 (VDD), LED15.2 (VDD), LED16.2 (VDD); also elsewhere on the board
5V_LED_SOURCE2: LED17.2 (VDD), LED18.2 (VDD), LED19.2 (VDD), LED20.2 (VDD), LED21.2 (VDD), LED22.2 (VDD), LED23.2 (VDD), LED24.2 (VDD), LED25.2 (VDD), LED26.2 (VDD), LED27.2 (VDD), LED28.2 (VDD), LED29.2 (VDD), LED30.2 (VDD), LED31.2 (VDD), LED32.2 (VDD); also elsewhere on the board
5V_LED_SOURCE3: LED33.2 (VDD), LED34.2 (VDD), LED35.2 (VDD), LED36.2 (VDD), LED37.2 (VDD), LED38.2 (VDD), LED39.2 (VDD), LED40.2 (VDD), LED41.2 (VDD), LED42.2 (VDD), LED43.2 (VDD), LED44.2 (VDD), LED45.2 (VDD), LED46.2 (VDD), LED47.2 (VDD), LED48.2 (VDD); also elsewhere on the board
5V_LED_SOURCE4: LED49.2 (VDD), LED50.2 (VDD), LED51.2 (VDD), LED52.2 (VDD), LED53.2 (VDD), LED54.2 (VDD), LED55.2 (VDD), LED56.2 (VDD), LED57.2 (VDD), LED58.2 (VDD), LED59.2 (VDD), LED60.2 (VDD), LED61.2 (VDD), LED62.2 (VDD), LED63.2 (VDD), LED64.2 (VDD); also elsewhere on the board
GND: LED1.4 (GND), LED2.4 (GND), LED3.4 (GND), LED4.4 (GND), LED5.4 (GND), LED6.4 (GND), LED7.4 (GND), LED8.4 (GND), LED9.4 (GND), LED10.4 (GND), LED11.4 (GND), LED12.4 (GND), LED13.4 (GND), LED14.4 (GND), LED15.4 (GND), LED16.4 (GND), LED17.4 (GND), LED18.4 (GND), LED19.4 (GND), LED20.4 (GND), LED21.4 (GND), LED22.4 (GND), LED23.4 (GND), LED24.4 (GND), LED25.4 (GND), LED26.4 (GND), LED27.4 (GND), LED28.4 (GND), LED29.4 (GND), LED30.4 (GND), LED31.4 (GND), LED32.4 (GND), LED33.4 (GND), LED34.4 (GND), LED35.4 (GND), LED36.4 (GND), LED37.4 (GND), LED38.4 (GND), LED39.4 (GND), LED40.4 (GND), LED41.4 (GND), LED42.4 (GND), LED43.4 (GND), LED44.4 (GND), LED45.4 (GND), LED46.4 (GND), LED47.4 (GND), LED48.4 (GND), LED49.4 (GND), LED50.4 (GND), LED51.4 (GND), LED52.4 (GND), LED53.4 (GND), LED54.4 (GND), LED55.4 (GND), LED56.4 (GND), LED57.4 (GND), LED58.4 (GND), LED59.4 (GND), LED60.4 (GND), LED61.4 (GND), LED62.4 (GND), LED63.4 (GND), LED64.4 (GND); also elsewhere on the board
LED_DATA: LED1.1 (DI); also elsewhere on the board
MATRIX_LED_DATA_OUT: LED57.3 (DO); also elsewhere on the board
unnamed: LED9.1 (DI), LED10.3 (DO)
unnamed: LED10.1 (DI), LED11.3 (DO)
unnamed: LED11.1 (DI), LED12.3 (DO)
unnamed: LED12.1 (DI), LED13.3 (DO)
unnamed: LED13.1 (DI), LED14.3 (DO)
unnamed: LED14.1 (DI), LED15.3 (DO)
unnamed: LED15.1 (DI), LED16.3 (DO)
unnamed: LED25.1 (DI), LED26.3 (DO)
unnamed: LED26.1 (DI), LED27.3 (DO)
unnamed: LED27.1 (DI), LED28.3 (DO)
unnamed: LED28.1 (DI), LED29.3 (DO)
unnamed: LED29.1 (DI), LED30.3 (DO)
unnamed: LED30.1 (DI), LED31.3 (DO)
unnamed: LED31.1 (DI), LED32.3 (DO)
unnamed: LED41.1 (DI), LED42.3 (DO)
unnamed: LED42.1 (DI), LED43.3 (DO)
unnamed: LED43.1 (DI), LED44.3 (DO)
unnamed: LED44.1 (DI), LED45.3 (DO)
unnamed: LED45.1 (DI), LED46.3 (DO)
unnamed: LED46.1 (DI), LED47.3 (DO)
unnamed: LED47.1 (DI), LED48.3 (DO)
unnamed: LED1.3 (DO), LED2.1 (DI)
unnamed: LED2.3 (DO), LED3.1 (DI)
unnamed: LED3.3 (DO), LED4.1 (DI)
unnamed: LED4.3 (DO), LED5.1 (DI)
unnamed: LED5.3 (DO), LED6.1 (DI)
unnamed: LED6.3 (DO), LED7.1 (DI)
unnamed: LED7.3 (DO), LED8.1 (DI)
unnamed: LED57.1 (DI), LED58.3 (DO)
unnamed: LED24.3 (DO), LED32.1 (DI)
unnamed: LED40.3 (DO), LED48.1 (DI)
unnamed: LED56.3 (DO), LED64.1 (DI)
unnamed: LED41.3 (DO), LED49.1 (DI)
unnamed: LED25.3 (DO), LED33.1 (DI)
unnamed: LED9.3 (DO), LED17.1 (DI)
unnamed: LED58.1 (DI), LED59.3 (DO)
unnamed: LED59.1 (DI), LED60.3 (DO)
unnamed: LED60.1 (DI), LED61.3 (DO)
unnamed: LED61.1 (DI), LED62.3 (DO)
unnamed: LED62.1 (DI), LED63.3 (DO)
unnamed: LED63.1 (DI), LED64.3 (DO)
unnamed: LED17.3 (DO), LED18.1 (DI)
unnamed: LED18.3 (DO), LED19.1 (DI)
unnamed: LED19.3 (DO), LED20.1 (DI)
unnamed: LED20.3 (DO), LED21.1 (DI)
unnamed: LED21.3 (DO), LED22.1 (DI)
unnamed: LED22.3 (DO), LED23.1 (DI)
unnamed: LED23.3 (DO), LED24.1 (DI)
unnamed: LED33.3 (DO), LED34.1 (DI)
unnamed: LED34.3 (DO), LED35.1 (DI)
unnamed: LED35.3 (DO), LED36.1 (DI)
unnamed: LED36.3 (DO), LED37.1 (DI)
unnamed: LED37.3 (DO), LED38.1 (DI)
unnamed: LED38.3 (DO), LED39.1 (DI)
unnamed: LED39.3 (DO), LED40.1 (DI)
unnamed: LED49.3 (DO), LED50.1 (DI)
unnamed: LED50.3 (DO), LED51.1 (DI)
unnamed: LED51.3 (DO), LED52.1 (DI)
unnamed: LED52.3 (DO), LED53.1 (DI)
unnamed: LED53.3 (DO), LED54.1 (DI)
unnamed: LED54.3 (DO), LED55.1 (DI)
unnamed: LED55.3 (DO), LED56.1 (DI)
unnamed: LED8.3 (DO), LED16.1 (DI)

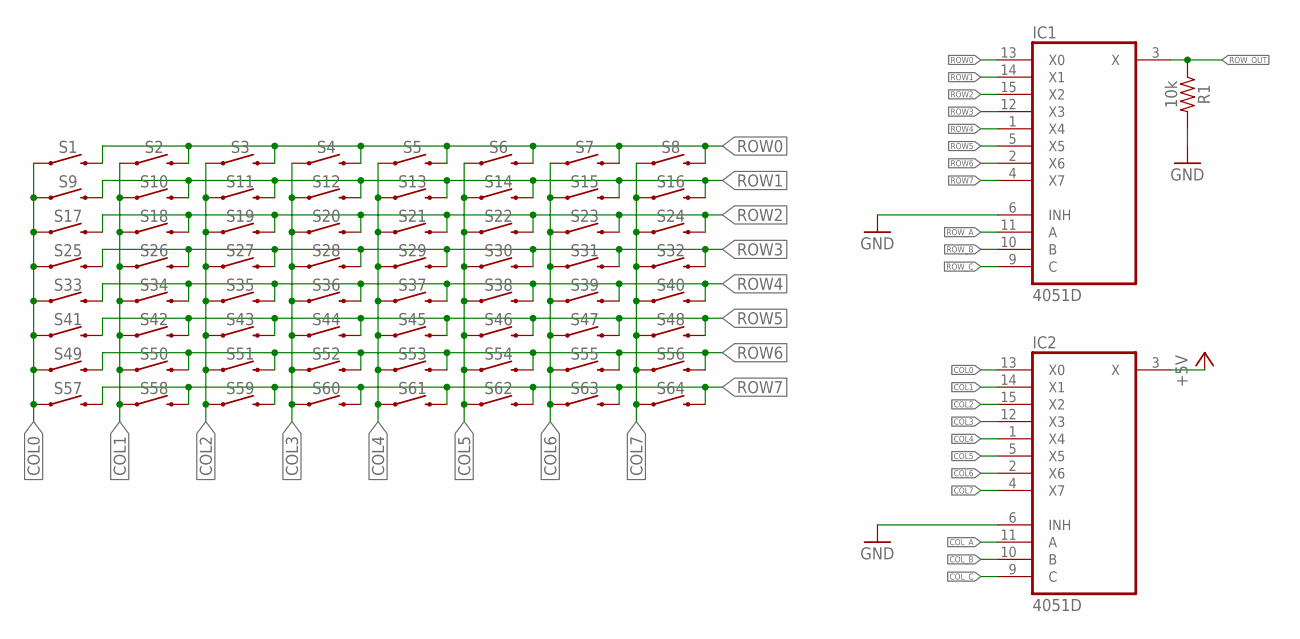
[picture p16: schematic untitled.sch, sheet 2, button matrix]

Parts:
IC1, IC2: 4051D; SO16
R1: 10k; 0603
S1, S2, S3, S4, S5, S6, S7, S8, S9, S10, S11, S12, S13, S14, S15, S16, S17, S18, S19, S20, S21, S22, S23, S24, S25, S26, S27, S28, S29, S30, S31, S32, S33, S34, S35, S36, S37, S38, S39, S40, S41, S42, S43, S44, S45, S46, S47, S48, S49, S50, S51, S52, S53, S54, S55, S56, S57, S58, S59, S60, S61, S62, S63, S64: MOMENTARY-SWITCH-SPST-SMD-6.0X3.5MM; TACTILE_SWITCH_SMD_6.0X3.5MM

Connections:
+5V: IC2.3 (X); also elsewhere on the board
COL0: IC2.13 (X0), S1.1, S9.1, S17.1, S25.1, S33.1, S41.1, S49.1, S57.1
COL1: IC2.14 (X1), S2.1, S10.1, S18.1, S26.1, S34.1, S42.1, S50.1, S58.1
COL2: IC2.15 (X2), S3.1, S11.1, S19.1, S27.1, S35.1, S43.1, S51.1, S59.1
COL3: IC2.12 (X3), S4.1, S12.1, S20.1, S28.1, S36.1, S44.1, S52.1, S60.1
COL4: IC2.1 (X4), S5.1, S13.1, S21.1, S29.1, S37.1, S45.1, S53.1, S61.1
COL5: IC2.5 (X5), S6.1, S14.1, S22.1, S30.1, S38.1, S46.1, S54.1, S62.1
COL6: IC2.2 (X6), S7.1, S15.1, S23.1, S31.1, S39.1, S47.1, S55.1, S63.1
COL7: IC2.4 (X7), S8.1, S16.1, S24.1, S32.1, S40.1, S48.1, S56.1, S64.1
COL_A: IC2.11 (A); also elsewhere on the board
COL_B: IC2.10 (B); also elsewhere on the board
COL_C: IC2.9 (C); also elsewhere on the board
GND: IC1.6 (INH), IC1.8 (GND), IC2.6 (INH), IC2.8 (GND), R1.2; also elsewhere on the board
ROW0: IC1.13 (X0), S1.2, S2.2, S3.2, S4.2, S5.2, S6.2, S7.2, S8.2
ROW1: IC1.14 (X1), S9.2, S10.2, S11.2, S12.2, S13.2, S14.2, S15.2, S16.2
ROW2: IC1.15 (X2), S17.2, S18.2, S19.2, S20.2, S21.2, S22.2, S23.2, S24.2
ROW3: IC1.12 (X3), S25.2, S26.2, S27.2, S28.2, S29.2, S30.2, S31.2, S32.2
ROW4: IC1.1 (X4), S33.2, S34.2, S35.2, S36.2, S37.2, S38.2, S39.2, S40.2
ROW5: IC1.5 (X5), S41.2, S42.2, S43.2, S44.2, S45.2, S46.2, S47.2, S48.2
ROW6: IC1.2 (X6), S49.2, S50.2, S51.2, S52.2, S53.2, S54.2, S55.2, S56.2
ROW7: IC1.4 (X7), S57.2, S58.2, S59.2, S60.2, S61.2, S62.2, S63.2, S64.2
ROW_A: IC1.11 (A); also elsewhere on the board
ROW_B: IC1.10 (B); also elsewhere on the board
ROW_C: IC1.9 (C); also elsewhere on the board
ROW_OUT: IC1.3 (X), R1.1; also elsewhere on the board
VCC: IC1.16 (VCC), IC2.16 (VCC); also elsewhere on the board
VEE: IC1.7 (VEE), IC2.7 (VEE); also elsewhere on the board

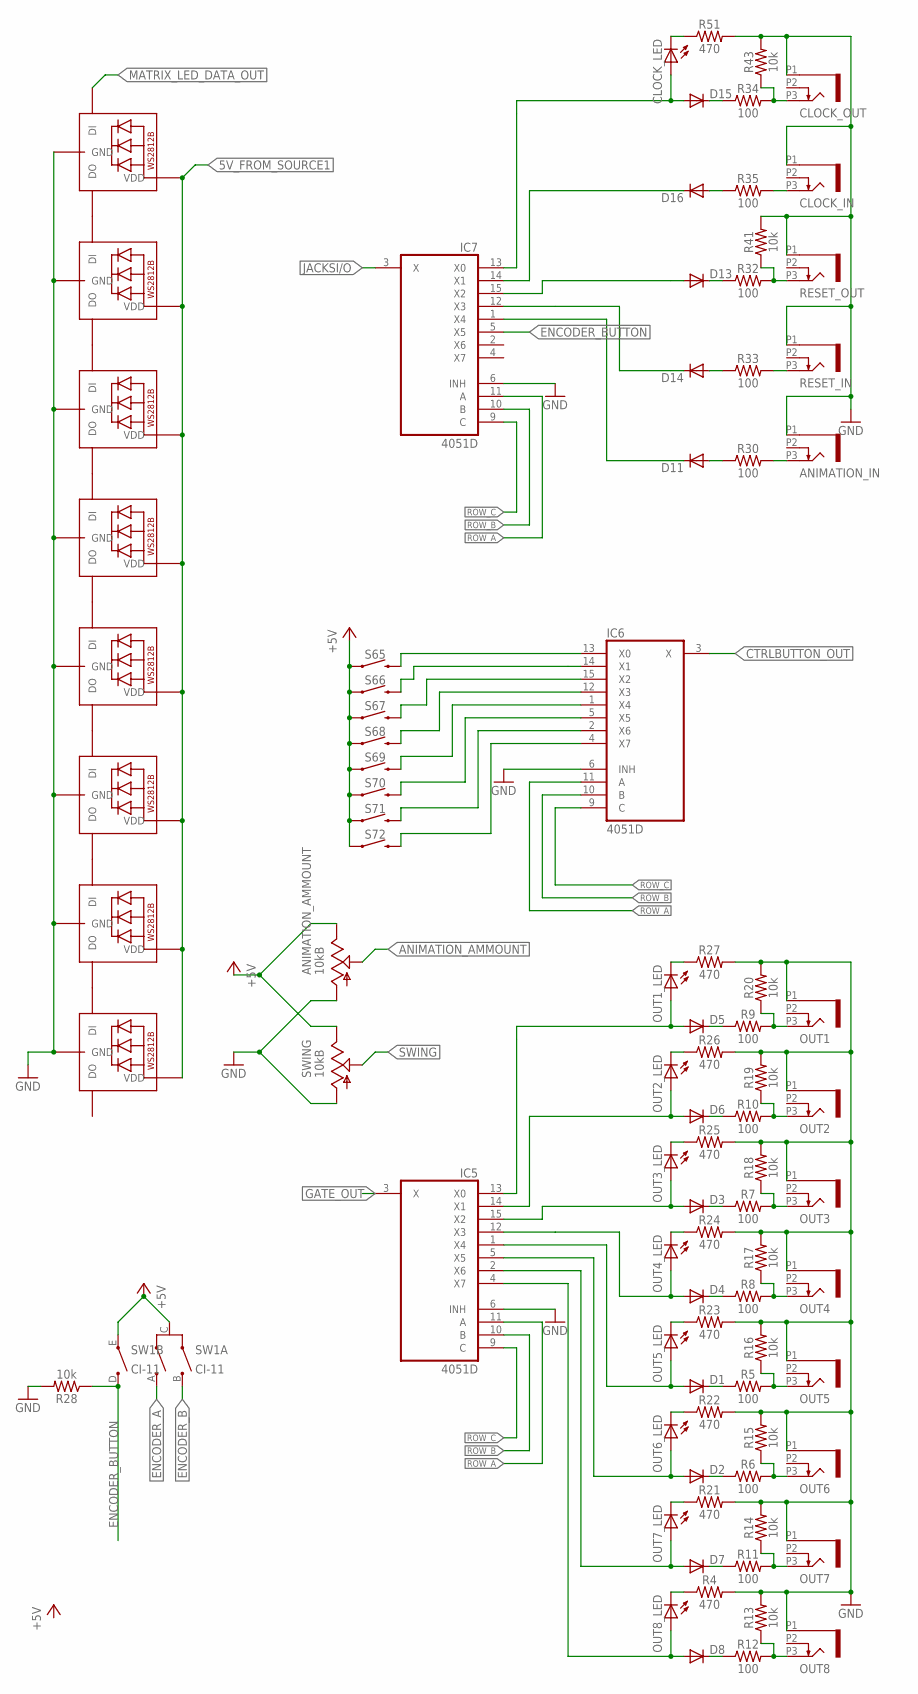
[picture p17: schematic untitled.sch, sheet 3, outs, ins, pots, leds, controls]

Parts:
ANIMATION_AMMOUNT: 10kB; ALPS_POT_VERTICAL
ANIMATION_IN: PJ301_THONKICONN8; WQP_PJ_301M8
CLOCK_IN: PJ301_THONKICONN1; WQP_PJ_301M1
CLOCK_LED: LED5MM
CLOCK_OUT: PJ301_THONKICONN1; WQP_PJ_301M1
D1, D2, D3, D4, D5, D6, D7, D8, D11, D13, D14, D15, D16: DIODE-DO214AC; DO214AC
IC5, IC6, IC7: 4051D; SO16
LED65, LED66, LED67, LED68, LED69, LED70, LED71, LED72: WS2812B3535; LED3535
OUT1, OUT2, OUT3, OUT4, OUT5, OUT6: PJ301_THONKICONN1; WQP_PJ_301M1
OUT1_LED, OUT2_LED, OUT3_LED, OUT4_LED, OUT5_LED, OUT6_LED, OUT7_LED, OUT8_LED: LED5MM
OUT7, OUT8: PJ301_THONKICONN8; WQP_PJ_301M8
R4, R21, R22, R23, R24, R25, R26, R27, R51: 470; 0603
R5, R6, R7, R8, R9, R10, R11, R12, R30, R32, R33, R34, R35: 100; 0603
R13, R14, R15, R16, R17, R18, R19, R20, R28, R41, R43: 10k; 0603
RESET_IN: PJ301_THONKICONN1; WQP_PJ_301M1
RESET_OUT: PJ301_THONKICONN8; WQP_PJ_301M8
S65, S66, S67, S68, S69, S70, S71, S72: MOMENTARY-SWITCH-SPST-SMD-6.0X3.5MM; TACTILE_SWITCH_SMD_6.0X3.5MM
SW1: CI-11
SWING: 10kB; ALPS_POT_VERTICAL

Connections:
5V_FROM_SOURCE1: LED65.2 (VDD), LED66.2 (VDD), LED67.2 (VDD), LED68.2 (VDD), LED69.2 (VDD), LED70.2 (VDD), LED71.2 (VDD), LED72.2 (VDD); also elsewhere on the board
+5V: ANIMATION_AMMOUNT.P$1 (E), S65.1, S66.1, S67.1, S68.1, S69.1, S70.1, S71.1, S72.1, SW1.C, SW1.E, SWING.P$1 (E); also elsewhere on the board
ANIMATION_AMMOUNT: ANIMATION_AMMOUNT.P$2 (S); also elsewhere on the board
CTRLBUTTON_OUT: IC6.3 (X); also elsewhere on the board
ENCODER_A: SW1.A; also elsewhere on the board
ENCODER_B: SW1.B; also elsewhere on the board
ENCODER_BUTTON: IC7.5 (X5), R28.1, SW1.D
GATE_OUT: IC5.3 (X); also elsewhere on the board
GND: ANIMATION_AMMOUNT.P$3 (A), ANIMATION_IN.P1 (1), CLOCK_IN.P1 (1), CLOCK_OUT.P1 (1), IC5.6 (INH), IC5.8 (GND), IC6.6 (INH), IC6.8 (GND), IC7.6 (INH), IC7.8 (GND), LED65.4 (GND), LED66.4 (GND), LED67.4 (GND), LED68.4 (GND), LED69.4 (GND), LED70.4 (GND), LED71.4 (GND), LED72.4 (GND), OUT1.P1 (1), OUT2.P1 (1), OUT3.P1 (1), OUT4.P1 (1), OUT5.P1 (1), OUT6.P1 (1), OUT7.P1 (1), OUT8.P1 (1), R4.2, R13.2, R14.2, R15.2, R16.2, R17.2, R18.2, R19.2, R20.2, R21.2, R22.2, R23.2, R24.2, R25.2, R26.2, R27.2, R28.2, R41.2, R43.2, R51.2, RESET_IN.P1 (1), RESET_OUT.P1 (1), SWING.P$3 (A); also elsewhere on the board
JACKSI/O: IC7.3 (X); also elsewhere on the board
MATRIX_LED_DATA_OUT: LED72.1 (DI); also elsewhere on the board
unnamed: D1.C, R5.1
unnamed: D2.C, R6.1
unnamed: OUT6.P3 (3), R6.2, R15.1
unnamed: OUT5.P3 (3), R5.2, R16.1
unnamed: D3.C, R7.1
unnamed: D4.C, R8.1
unnamed: D7.C, R11.1
unnamed: D8.C, R12.1
unnamed: OUT8.P3 (3), R12.2, R13.1
unnamed: OUT7.P3 (3), R11.2, R14.1
unnamed: OUT4.P3 (3), R8.2, R17.1
unnamed: OUT3.P3 (3), R7.2, R18.1
unnamed: D5.C, R9.1
unnamed: D6.C, R10.1
unnamed: OUT2.P3 (3), R10.2, R19.1
unnamed: OUT1.P3 (3), R9.2, R20.1
unnamed: D5.A, IC5.13 (X0), OUT1_LED.A
unnamed: D6.A, IC5.14 (X1), OUT2_LED.A
unnamed: D3.A, IC5.15 (X2), OUT3_LED.A
unnamed: D4.A, IC5.12 (X3), OUT4_LED.A
unnamed: D1.A, IC5.1 (X4), OUT5_LED.A
unnamed: D2.A, IC5.5 (X5), OUT6_LED.A
unnamed: D7.A, IC5.2 (X6), OUT7_LED.A
unnamed: D8.A, IC5.4 (X7), OUT8_LED.A
unnamed: LED65.3 (DO), LED66.1 (DI)
unnamed: LED65.1 (DI), LED70.3 (DO)
unnamed: LED66.3 (DO), LED67.1 (DI)
unnamed: LED67.3 (DO), LED68.1 (DI)
unnamed: LED68.3 (DO), LED69.1 (DI)
unnamed: LED69.3 (DO), LED71.1 (DI)
unnamed: LED70.1 (DI), LED72.3 (DO)
unnamed: OUT1_LED.K (C), R27.1
unnamed: OUT2_LED.K (C), R26.1
unnamed: OUT3_LED.K (C), R25.1
unnamed: OUT4_LED.K (C), R24.1
unnamed: OUT5_LED.K (C), R23.1
unnamed: OUT6_LED.K (C), R22.1
unnamed: OUT7_LED.K (C), R21.1
unnamed: OUT8_LED.K (C), R4.1
unnamed: D16.A, R35.1
unnamed: D14.A, R33.1
unnamed: D11.A, R30.1
unnamed: ANIMATION_IN.P3 (3), R30.2
unnamed: D13.C, R32.1
unnamed: R33.2, RESET_IN.P3 (3)
unnamed: R32.2, R41.1, RESET_OUT.P3 (3)
unnamed: D15.C, R34.1
unnamed: CLOCK_IN.P3 (3), R35.2
unnamed: CLOCK_OUT.P3 (3), R34.2, R43.1
unnamed: CLOCK_LED.A, D15.A, IC7.13 (X0)
unnamed: D16.C, IC7.14 (X1)
unnamed: D13.A, IC7.15 (X2)
unnamed: D14.C, IC7.12 (X3)
unnamed: D11.C, IC7.1 (X4)
unnamed: CLOCK_LED.K (C), R51.1
ROW8: IC6.13 (X0), S65.2
ROW9: IC6.14 (X1), S66.2
ROW10: IC6.15 (X2), S67.2
ROW11: IC6.12 (X3), S68.2
ROW12: IC6.1 (X4), S69.2
ROW13: IC6.5 (X5), S70.2
ROW14: IC6.2 (X6), S71.2
ROW15: IC6.4 (X7), S72.2
ROW_A: IC5.11 (A), IC6.11 (A), IC7.11 (A); also elsewhere on the board
ROW_B: IC5.10 (B), IC6.10 (B), IC7.10 (B); also elsewhere on the board
ROW_C: IC5.9 (C), IC6.9 (C), IC7.9 (C); also elsewhere on the board
SWING: SWING.P$2 (S); also elsewhere on the board
VCC: IC5.16 (VCC), IC6.16 (VCC), IC7.16 (VCC); also elsewhere on the board
VEE: IC5.7 (VEE), IC6.7 (VEE), IC7.7 (VEE); also elsewhere on the board

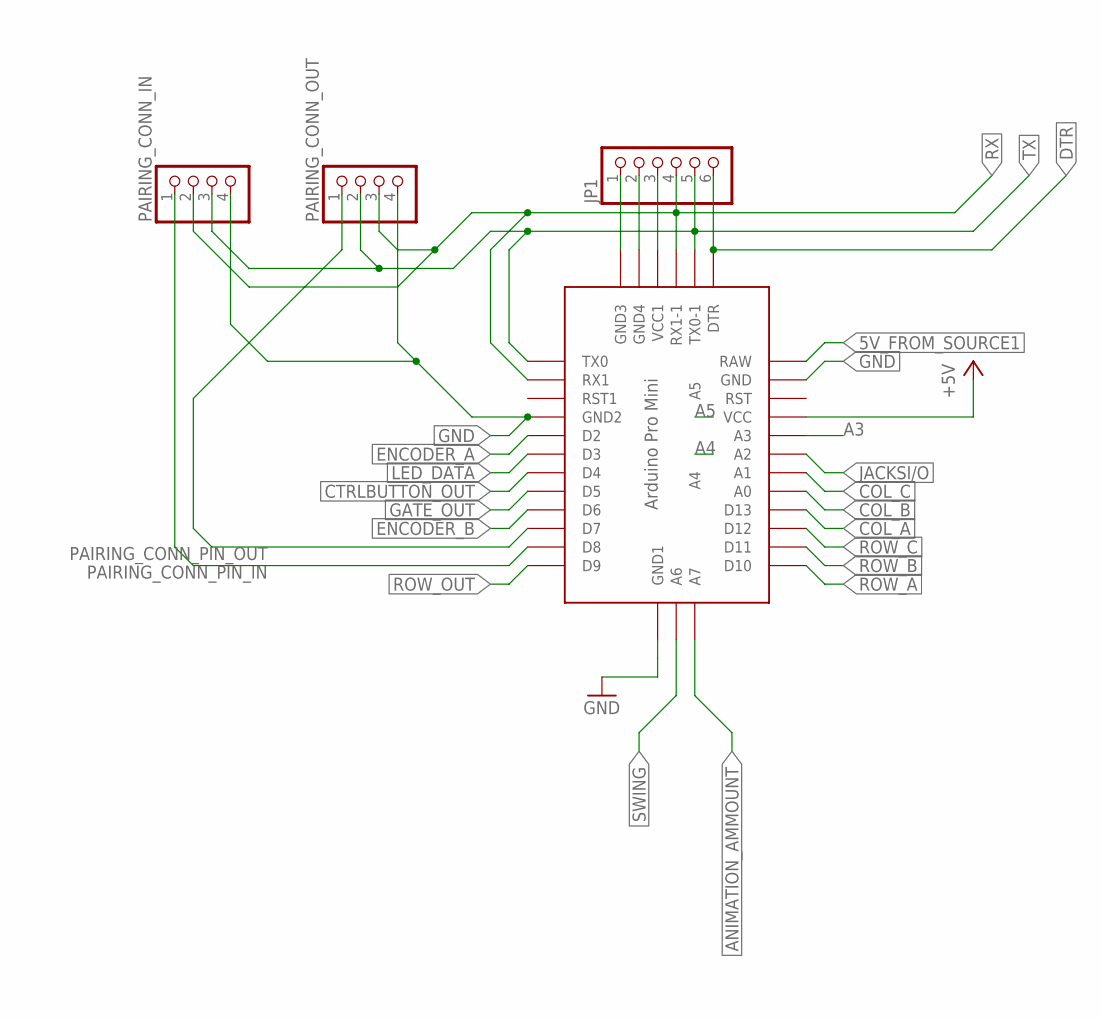
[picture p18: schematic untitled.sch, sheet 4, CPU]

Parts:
JP1: PINHD-1X6; 1X06
PAIRING_CONN_IN: PINHD-1X4; 1X04
PAIRING_CONN_OUT: PINHD-1X4; 1X04
U$1: ABK-PRO-MINI

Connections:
5V_FROM_SOURCE1: U$1.RAW; also elsewhere on the board
+5V: JP1.3, U$1.VCC, U$1.VCC1; also elsewhere on the board
A3: U$1.A3
A4: U$1.A4
A5: U$1.A5
ANIMATION_AMMOUNT: U$1.A7; also elsewhere on the board
COL_A: U$1.D13; also elsewhere on the board
COL_B: U$1.A0; also elsewhere on the board
COL_C: U$1.A1; also elsewhere on the board
CTRLBUTTON_OUT: U$1.D4; also elsewhere on the board
DTR: JP1.6, U$1.DTR; also elsewhere on the board
ENCODER_A: U$1.D2; also elsewhere on the board
ENCODER_B: U$1.D6; also elsewhere on the board
GATE_OUT: U$1.D5; also elsewhere on the board
GND: JP1.1, JP1.2, PAIRING_CONN_IN.4, PAIRING_CONN_OUT.4, U$1.GND, U$1.GND1 (GND2), U$1.GND2 (GND3), U$1.GND3 (GND4), U$1.GND4 (GND1); also elsewhere on the board
JACKSI/O: U$1.A2; also elsewhere on the board
LED_DATA: U$1.D3; also elsewhere on the board
PAIRING_CONN_PIN_IN: PAIRING_CONN_IN.1, U$1.D8
PAIRING_CONN_PIN_OUT: PAIRING_CONN_OUT.1, U$1.D7
ROW_A: U$1.D10; also elsewhere on the board
ROW_B: U$1.D11; also elsewhere on the board
ROW_C: U$1.D12; also elsewhere on the board
ROW_OUT: U$1.D9; also elsewhere on the board
RX: JP1.4, PAIRING_CONN_IN.2, PAIRING_CONN_OUT.3, U$1.RX1, U$1.RX1-1; also elsewhere on the board
SWING: U$1.A6; also elsewhere on the board
TX: JP1.5, PAIRING_CONN_IN.3, PAIRING_CONN_OUT.2, U$1.TX0, U$1.TX0-1; also elsewhere on the board


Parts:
C6, C8: 0.1uF; 0603
C7: 10uF; 0603
IC4: FT232RL; SSOP28
R2, R3: 470; 0603
RXLED-GREEN: LEDCHIP-LED0603; CHIP-LED0603
TXLED-BLUE: LEDCHIP-LED0603; CHIP-LED0603
U$2: PTC-FUSE; 1206
X1: USB-B-S; USB-B-SMT

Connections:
+5V: C7.1, C8.2, IC4.4 (VCCIO), IC4.20 (VCC), R2.1, R3.1, U$2.1; also elsewhere on the board
DTR: IC4.2 (!DTR); also elsewhere on the board
GND: C6.1, C7.2, C8.1, IC4.7 (GND), IC4.11 (!CTS), IC4.18 (GND), IC4.21 (GND), IC4.25 (GND), IC4.26 (TEST), X1.GND; also elsewhere on the board
unnamed: R2.2, TXLED-BLUE.A
unnamed: R3.2, RXLED-GREEN.A
unnamed: U$2.2, X1.VUSB (VBUS)
unnamed: IC4.23 (CBUS0), TXLED-BLUE.C
unnamed: IC4.22 (CBUS1), RXLED-GREEN.C
unnamed: IC4.15 (USBDP), X1.D+
unnamed: IC4.16 (USBDM), X1.D-
unnamed: C6.2, IC4.17 (3V3OUT)
RX: IC4.1 (TXD); also elsewhere on the board
TX: IC4.5 (RXD); also elsewhere on the board


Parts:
C1, C2, C3, C4, C5: 0.1uF; 0603
D9: 1N5819HW; SOD123
IC3, IC8, IC9, IC10, IC11: 7805DT; TO252
U$3: POWER_SIMPLE10; POWER_10
U$4: PTC-FUSE; 1206

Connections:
5V_FROM_SOURCE1: IC3.2 (VO); also elsewhere on the board
5V_LED_SOURCE1: IC8.2 (VO); also elsewhere on the board
5V_LED_SOURCE2: IC9.2 (VO); also elsewhere on the board
5V_LED_SOURCE3: IC10.2 (VO); also elsewhere on the board
5V_LED_SOURCE4: IC11.2 (VO); also elsewhere on the board
+5V: C1.1, C2.1, C3.1, C4.1, C5.1; also elsewhere on the board
GND: C1.2, C2.2, C3.2, C4.2, C5.2, IC3.3 (GND), IC8.3 (GND), IC9.3 (GND), IC10.3 (GND), IC11.3 (GND), U$3.3 (GND), U$3.4 (GND), U$3.5 (GND), U$3.6 (GND), U$3.7 (GND), U$3.8 (GND); also elsewhere on the board
unnamed: IC8.1 (VI), IC9.1 (VI), IC10.1 (VI), IC11.1 (VI), U$3.9 (+12V), U$3.10 (+12V), U$4.2
unnamed: D9.A, U$4.1
unnamed: D9.C, IC3.1 (VI)



Board: 2 copper layers, 176.5 x 111.4 mm, 248 parts (78 on the bottom side), 184 nets.

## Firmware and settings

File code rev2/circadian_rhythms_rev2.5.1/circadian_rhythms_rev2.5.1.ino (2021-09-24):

//pcb rev 2.0
#include <FastLED.h> //https://github.com/FastLED/FastLED
#include <EEPROM.h> //already built in with arduino IDE
#include <avr/pgmspace.h> //already built in with arduino IDE (https://www.nongnu.org/avr-libc/user-manual/group__avr__pgmspace.html)

/*NOTES
   buttons are red top to bottom > left to right
*/

#define SPEED_DEBUG 2
/* SPEED_DEBUG types
 * 0 - none
 * 1 - overall with the printing itself excluded
 * 2 - overall with the printing and LEDs excluded
 */

//arduino pin
#define encoderA 2
#define encoderB 11
#define encoderS 12
#define clockInPin 3
#define commA 4
#define commB 5
#define commC 6
#define buttonColOut 7
#define buttonRowPulse 8
#define ledPin 9
#define buttonMenuOut 10
#define resetIn 13
#define regL 14
#define regC 15
#define dacD 16
#define regD 17
#define buttonRowReset 18
#define anaMux 21
//shiftreg
#define dacCS 0
#define clockOut 1
#define resetOut 2
#define clockResetSwitch 3
#define dacLdac 5

//nonreal values
#define keyPressDuration 300
#define longPressDuration 1000
#define triggerLenght 20
#define hardwareClockTimerFrquency (F_CPU * 60) //precalculate the left part of the claculation with crystal frequency
#define BPMTimeout 400
#define SYSfirmwareVersion "2.5.1 current firmware."

//EEPROM positions
#define EEPROMBPM 1000
#define EEPROMLastSavedTo 1001
#define EEPROMLastLoadedFrom 1002
#define EEPROMClockMultiplier 1003 //has 100 added to it so it allways is an integer
#define EEPROMClockSource 1004
#define EEPROMGateTrigger 1005
#define EEPROMUsedCheck 1023 //this position has to be eaqul to 17, if it is not, it will reset all adresses

uint8_t counter;
bool menuButton[9];
bool menuButtonLast[9];
bool buttonState[65];
bool buttonStatePrev[65];
uint64_t currentSequence[9];
uint64_t currentAccents[9];
uint64_t nextSequence[9];
uint64_t nextAccents[9];
uint8_t jackState;
uint8_t controlReg;
uint8_t brightnessAdj;
uint8_t temperatureAdj;
float temperatureSens;
uint16_t variable1Adj;
uint16_t variable2Adj;
uint8_t verticalBtnScanPrev;
uint8_t channelZoom;
uint8_t sequenceLenght = 63;
uint8_t masterClock;
bool gate2TriggerClockToggle;
bool gate2TriggerTimerRunning;
int16_t scrollStringPosition;
uint8_t helpInfoTextPrev;
uint8_t helpInfoText;
uint8_t helpInfoVariable;
uint8_t displayButtonMode = 0;
bool encoderSwitchPrev;
uint8_t encoderClosedMenu;
uint8_t gateTriggerChannel;
uint8_t buttonUIChannelZoomBeforeZero;
bool menuButtonShiftActive;
bool menuButtonShiftActivePrev;
bool clockRunning = 1;
bool clockSource = 0; //1 internal, 0 external
uint32_t blinkMainCounter;
bool blink20msState;
bool blink40msState;
bool blink80msState;
bool blink160msState;
uint8_t globalInternalBPM = 120;
uint8_t globalInternalSwing = 0;
int8_t clockMultiplier = 1;
uint16_t compareNumberPrev;
bool DisableControlLeds;
bool clockMultipliButtonPrev;
bool clockDivideButtonPrev;
uint8_t lastSavedTo;
uint8_t lastLoadedFrom;
uint8_t nextSequenceReady = 255; //default state is 255 because 0 is a valid loading position
uint16_t clockInputSpeed;
bool clockResetJacksSourcePrev;
uint8_t modeSavingPrev;
uint8_t ledUIModePrev;
uint8_t ledUIClockPrev = 1; //the clock var might startoff as 0 and therefor it wont render the pixel on first launch
CRGB ledUIClockColor; //CRGB is a special FastLED datatype (three bytes) - It has to be this specific datatype so you can read colors directly
uint8_t ledUIStepPrev = 1; //the step var might startoff as 0 and therefor it wont render the pixel on first launch
CRGB ledUIStepColor;
bool refreshLedAfterHelp;


uint32_t showLedPMill;
uint32_t gate2triggerPMill;
uint32_t scrollStringPMill;
uint32_t buttonPMill;
uint32_t menuButtonPMill;
uint32_t encoderSwitchPMill;
uint32_t testMeasuringPMill;
uint32_t blinkMainPMill;
uint32_t displayBPMPMill;
uint32_t clockMeasuringPMill;

CRGB leds[72];

static const uint8_t controlLeds[9] = {64, 65, 66, 67, 68, 69, 70 , 71};
static const uint8_t ledMatrix[10][9] = { //x(horizontal) ,y(vertical)
  {0, 15, 16, 31, 32, 47, 48, 63},
  {1, 14, 17, 30, 33, 46, 49, 62},
  {2, 13, 18, 29, 34, 45, 50, 61},
  {3, 12, 19, 28, 35, 44, 51, 60},
  {4, 11, 20, 27, 36, 43, 52, 59},
  {5, 10, 21, 26, 37, 42, 53, 58},
  {6, 9, 22, 25, 38, 41, 54, 57},
  {7, 8, 23, 24, 39, 40, 55, 56},
  {64, 65, 66, 67, 68, 69, 70, 71},
};
static const uint8_t buttonMatrix[9][9] = { //x(horizontal) ,y(vertical)
  {0  ,  1,  2,  3,  4,  5,  6,  7},
  {8  ,  9, 10, 11, 12, 13, 14, 15},
  {16 , 17, 18, 19, 20, 21, 22, 23},
  {24 , 25, 26, 27, 28, 29, 30, 31},
  {32 , 33, 34, 35, 36, 37, 38, 39},
  {40 , 41, 42, 43, 44, 45, 46, 47},
  {48 , 49, 50, 51, 52, 53, 54, 55},
  {56 , 57, 58, 59, 60, 61, 62, 63},
};
/*----------FONT-7x8-version-1----------
   ---       ---   0   --- 00 00 ---   0 0 ---   0   ---  0    ---       ---   0   ---     0 --- 0     ---       ---       ---
   ---       ---   0   --- 0  0  ---   0 0 ---  000  --- 0 0   ---   00  ---   0   ---     0 --- 0     ---   0   ---   0   ---
   ---       ---   0   ---       ---  0 0  --- 0     ---  0    ---  0    ---   0   ---    0  ---  0    --- 00000 ---   0   ---
   ---       ---   0   ---       --- 00000 --- 0     ---    00 ---  0    ---       ---    0  ---  0    ---   0   ---   0   ---
   ---       ---   0   ---       ---  0 0  ---  000  --- 000   --- 0 0 0 ---       ---    0  ---  0    ---  0 0  ---0000000---
   ---       ---       ---       --- 00000 --- 0  0  ---    0  --- 0  0  ---       ---    0  ---  0    ---  0 0  ---   0   ---
   ---       ---       ---       ---  0 0  --- 000   ---   0 0 ---  00 0 ---       ---     0 --- 0     ---       ---   0   ---
   ---       ---   0   ---       --- 0 0   ---   0   ---    0  ---       ---       ---     0 --- 0     ---       ---   0   ---

   ---       ---       ---       ---    0  ---  000  ---  00   ---  000  ---  000  ---    00 ---  0000 ---   000 --- 00000 ---
   ---       ---       ---       ---    0  --- 0   0 ---   0   --- 0   0 --- 0   0 ---   0 0 ---  0    ---  0    --- 0   0 ---
   ---       ---       ---       ---   0   --- 0   0 ---   0   ---     0 ---     0 ---   0 0 ---  0    --- 0     ---     0 ---
   ---       ---       ---       ---   0   --- 0   0 ---   0   ---    0  ---   00  ---  0  0 ---  000  --- 0000  ---    0  ---
   ---  00   ---0000000---       ---  0    --- 0   0 ---   0   ---   0   ---     0 --- 0   0 ---     0 --- 0   0 ---    0  ---
   ---  0    ---       ---       ---  0    --- 0   0 ---   0   ---  0    ---     0 --- 000000---     0 --- 0   0 ---    0  ---
   --- 00    ---       ---  00   --- 0     --- 0   0 ---   0   --- 0   0 --- 0   0 ---     0 --- 0   0 --- 0   0 ---   0   ---
   --- 0     ---       ---  00   --- 0     ---  000  --- 00000 --- 00000 ---  000  ---    000---  000  ---  000  ---   0   ---

   ---  000  ---  000  ---       ---       ---       ---       ---       ---       ---  000  ---  00   ---00000  ---  0000 ---
   --- 0   0 --- 0   0 ---       ---       ---    00 ---       --- 00    ---  00   --- 0   0 ---   0   --- 0   0 --- 0   0 ---
   --- 0   0 --- 0   0 ---  00   ---  00   ---   0   ---       ---   0   --- 0  0  --- 0  00 ---  0 0  --- 0   0 --- 0     ---
   ---  000  --- 0   0 ---  00   ---  00   --- 00    ---0000000---    00 ---    0  --- 0 0 0 ---  0 0  --- 0000  --- 0     ---
   --- 0   0 ---  0000 ---       ---       ---0      ---       ---      0---   0   --- 0 0 0 --- 0   0 --- 0   0 --- 0     ---
   --- 0   0 ---     0 ---       ---  00   --- 00    ---0000000---    00 ---  0    --- 0  00 --- 00000 --- 0   0 --- 0     ---
   --- 0   0 ---    0  ---  00   --- 00    ---   0   ---       ---   0   ---       --- 0     --- 0   0 --- 0   0 --- 0   0 ---
   ---  000  --- 000   ---  00   --- 0     ---    00 ---       --- 00    ---  0    ---  000  ---000 000---00000  ---  000  ---

   ---0000   ---000000 ---000000 --- 0000  ---000 000--- 00000 ---  0000 ---000 000--- 000   ---000 000---000 000---  000  ---
   --- 0  0  --- 0   0 --- 0   0 ---0    0 --- 0   0 ---   0   ---    0  --- 0   0 ---  0    --- 00 00 --- 00  0 --- 0   0 ---
   --- 0   0 --- 0 0   --- 0 0   ---0      --- 0   0 ---   0   ---    0  --- 0  0  ---  0    --- 00 00 --- 00  0 --- 0   0 ---
   --- 0   0 --- 000   --- 000   ---0      --- 00000 ---   0   ---    0  --- 0 0   ---  0    --- 0 0 0 --- 0 0 0 --- 0   0 ---
   --- 0   0 --- 0 0   --- 0 0   ---0  000 --- 0   0 ---   0   ---    0  --- 000   ---  0    --- 0 0 0 --- 0 0 0 --- 0   0 ---
   --- 0   0 --- 0     --- 0     ---0   0  --- 0   0 ---   0   --- 0  0  --- 0  0  ---  0    --- 0   0 --- 0 0 0 --- 0   0 ---
   --- 0  0  --- 0   0 --- 0     ---0   0  --- 0   0 ---   0   --- 0  0  --- 0   0 ---  0  0 --- 0   0 --- 0  00 --- 0   0 ---
   ---0000   ---000000 ---000    --- 000   ---000 000--- 00000 ---  00   ---000 000--- 00000 ---000 000---000 000---  000  ---

   --- 0000  ---  000  ---00000  ---  00 0 ---0000000---000 000---000 000---000 000---00   00---000 000--- 00000 ---   000 ---
   ---  0  0 --- 0   0 --- 0   0 --- 0  00 ---0  0  0--- 0   0 --- 0   0 --- 0   0 --- 0   0 --- 0   0 --- 0   0 ---   0   ---
   ---  0  0 --- 0   0 --- 0   0 --- 0     ---   0   --- 0   0 --- 0   0 --- 0   0 ---  0 0  ---  0 0  ---    0  ---   0   ---
   ---  000  --- 0   0 --- 0000  ---  000  ---   0   --- 0   0 ---  0 0  --- 0 0 0 ---   0   ---  0 0  ---   0   ---   0   ---
   ---  0    --- 0   0 --- 0  0  ---     0 ---   0   --- 0   0 ---  0 0  --- 0 0 0 ---   0   ---   0   ---   0   ---   0   ---
   ---  0    --- 0   0 --- 0  0  ---     0 ---   0   --- 0   0 ---  0 0  --- 0 0 0 ---  0 0  ---   0   ---  0    ---   0   ---
   ---  0    ---  000  --- 0   0 --- 00  0 ---   0   --- 0   0 ---   0   --- 0 0 0 --- 0   0 ---   0   --- 0   0 ---   0   ---
   --- 000   ---   000 ---000   0--- 0 00  ---  000  ---  000  ---   0   ---  0 0  ---00   00---  000  --- 00000 ---   000 ---

   --- 0     --- 000   ---   0   ---       --- 0     ---       ---       ---       ---       ---       ---       ---       ---
   --- 0     ---   0   ---   0   ---       ---  0    ---       ---00     ---       ---     00---       ---   000 ---  00 00---
   ---  0    ---   0   ---  0 0  ---       ---       --- 000   --- 0     ---  0000 ---     0 ---  000  ---  0    --- 0  00 ---
   ---  0    ---   0   --- 0   0 ---       ---       ---0   0  --- 0 00  --- 0   0 ---  00 0 --- 0   0 --- 00000 --- 0   0 ---
   ---   0   ---   0   ---       ---       ---       --- 0000  --- 00  0 --- 0     --- 0  00 --- 00000 ---  0    --- 0   0 ---
   ---   0   ---   0   ---       ---       ---       ---0   0  --- 0   0 --- 0     --- 0   0 --- 0     ---  0    ---  0000 ---
   ---    0  ---   0   ---       ---       ---       ---0   0  --- 0   0 --- 0   0 --- 0   0 --- 0     ---  0    ---     0 ---
   ---    0  --- 000   ---       ---0000000---       --- 00000 ---00000  ---  000  ---  00000---  0000 --- 00000 ---  000  ---

   ---       ---       ---       ---       ---       ---       ---       ---       --- 00 00 ---  00 00---       ---       ---
   ---00     ---   0   ---   0   ---00     ---  00   ---       ---       ---       ---  00  0--- 0  00 ---       ---       ---
   --- 0     ---       ---       --- 0 000 ---   0   ---000 0  ---00 00  ---  000  ---  0   0--- 0   0 ---  00 00---  0000 ---
   --- 0 00  --- 000   --- 0000  --- 0  0  ---   0   --- 0 0 0 --- 00  0 --- 0   0 ---  0   0--- 0   0 ---   00  --- 0   0 ---
   --- 00  0 ---   0   ---    0  --- 000   ---   0   --- 0 0 0 --- 0   0 --- 0   0 ---  0   0--- 0   0 ---   0   ---  000  ---
   --- 0   0 ---   0   ---    0  --- 0 0   ---   0   --- 0 0 0 --- 0   0 --- 0   0 ---  0000 ---  0000 ---   0   ---     0 ---
   --- 0   0 ---   0   ---    0  --- 0  0  ---   0   --- 0 0 0 --- 0   0 --- 0   0 ---  0    ---     0 ---   0   --- 0   0 ---
   ---000 000--- 00000 --- 000   ---00 000 --- 00000 ---0000000---000 000---  000  --- 000   ---    000---- 0000 --- 0000  ---

   ---       ---       ---       ---       ---       ---       ---       ---     0 ---   0   --- 0     ---       ---
   --- 0     ---       ---       ---       ---       ---       ---       ---    0  ---   0   ---  0    ---       ---
   ---00000  ---00  00 ---000 000---000 000---00  00 ---000 000--- 00000 ---    0  ---   0   ---  0    ---       ---
   --- 0     --- 0   0 --- 0   0 --- 0   0 --- 0  0  --- 0   0 --- 0  0  ---    0  ---   0   ---  0    ---  0  0 ---
   --- 0     --- 0   0 --- 0   0 --- 0 0 0 ---  00   ---  0 0  ---   0   ---   0   ---   0   ---   0   --- 0 00  ---
   --- 0     --- 0   0 ---  0 0  --- 0 0 0 ---  00   ---   00  ---  0    ---    0  ---   0   ---  0    ---       ---
   --- 0   0 --- 0  00 ---  0 0  --- 0 0 0 --- 0  0  ---   0   --- 0   0 ---    0  ---   0   ---  0    ---       ---
   ---  000  ---  00 00---   0   ---  0 0  ---00  00 --- 0000  --- 00000 ---     0 ---   0   --- 0     ---       ---
*/
static const uint8_t FontArial7x8v1[] PROGMEM = {
  0x0F, 0xDE, // size
  0x07, // width
  0x08, // height
  0x20, // first char
  0x60, // char count

  // char widths
  0x03, 0x01, 0x05, 0x05, 0x04, 0x05, 0x05, 0x01, 0x02, 0x02,
  0x05, 0x05, 0x03, 0x05, 0x02, 0x04, 0x05, 0x05, 0x05, 0x05,
  0x06, 0x05, 0x05, 0x05, 0x05, 0x05, 0x02, 0x03, 0x06, 0x05,
  0x06, 0x04, 0x05, 0x07, 0x06, 0x05, 0x06, 0x06, 0x06, 0x07,
  0x07, 0x05, 0x05, 0x07, 0x05, 0x07, 0x07, 0x05, 0x05, 0x05,
  0x07, 0x05, 0x07, 0x07, 0x07, 0x07, 0x07, 0x07, 0x05, 0x03,
  0x04, 0x03, 0x05, 0x07, 0x02, 0x06, 0x06, 0x05, 0x06, 0x05,
  0x05, 0x06, 0x07, 0x05, 0x05, 0x06, 0x05, 0x07, 0x07, 0x05,
  0x06, 0x06, 0x05, 0x05, 0x06, 0x07, 0x07, 0x07, 0x06, 0x07,
  0x05, 0x03, 0x01, 0x03, 0x05, 0x07,

  // font data
  0x00, 0x00, 0x00, // 32
  0x9F, // 33
  0x03, 0x01, 0x00, 0x03, 0x01, // 34
  0xA8, 0x7C, 0xAB, 0x7C, 0x2B, // 35
  0x6C, 0x52, 0xD3, 0x32, // 36
  0x12, 0x15, 0x52, 0xA8, 0x48, // 37
  0x30, 0x4C, 0x52, 0x22, 0x50, // 38
  0x07, // 39
  0x3C, 0xC3, // 40
  0xC3, 0x3C, // 41
  0x04, 0x34, 0x0E, 0x34, 0x04, // 42
  0x10, 0x10, 0x7C, 0x10, 0x10, // 43
  0xC0, 0x70, 0x10, // 44
  0x10, 0x10, 0x10, 0x10, 0x10, // 45
  0xC0, 0xC0, // 46
  0xC0, 0x30, 0x0C, 0x03, // 47
  0x7E, 0x81, 0x81, 0x81, 0x7E, // 48
  0x80, 0x81, 0xFF, 0x80, 0x80, // 49
  0xC2, 0xA1, 0x91, 0x89, 0xC6, // 50
  0x42, 0x81, 0x89, 0x89, 0x76, // 51
  0x30, 0x28, 0x26, 0xA1, 0xFF, 0xA0, // 52
  0x40, 0x8F, 0x89, 0x89, 0x71, // 53
  0x7C, 0x8A, 0x89, 0x89, 0x71, // 54
  0x03, 0x01, 0xC1, 0x39, 0x07, // 55
  0x76, 0x89, 0x89, 0x89, 0x76, // 56
  0x8E, 0x91, 0x91, 0x51, 0x3E, // 57
  0xCC, 0xCC, // 58
  0xC0, 0x6C, 0x2C, // 59
  0x10, 0x28, 0x28, 0x44, 0x82, 0x82, // 60
  0x28, 0x28, 0x28, 0x28, 0x28, // 61
  0x82, 0x82, 0x44, 0x28, 0x28, 0x10, // 62
  0x04, 0xA2, 0x12, 0x0C, // 63
  0x7E, 0x81, 0x99, 0xA5, 0x3E, // 64
  0x80, 0xF0, 0xAD, 0x23, 0xAC, 0xF0, 0x80, // 65
  0x81, 0xFF, 0x89, 0x89, 0x76, 0x00, // 66
  0x7E, 0x81, 0x81, 0x81, 0x43, // 67
  0x81, 0xFF, 0x81, 0x81, 0x7E, 0x00, // 68
  0x81, 0xFF, 0x89, 0x9D, 0x81, 0xC3, // 69
  0x81, 0xFF, 0x91, 0x39, 0x01, 0x03, // 70
  0x7E, 0x81, 0x81, 0x81, 0x91, 0x72, 0x10, // 71
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

};
static const uint8_t FontGeneric3x6v1[] PROGMEM = {
  0x06, 0x90, // size
  0x03, // width
  0x06, // height
  0x20, // first char
  0x60, // char count

  // char widths
  0x02, 0x01, 0x03, 0x03, 0x03, 0x03, 0x03, 0x01, 0x02, 0x02,
  0x03, 0x03, 0x01, 0x03, 0x01, 0x03, 0x03, 0x02, 0x03, 0x03,
  0x03, 0x03, 0x03, 0x03, 0x03, 0x03, 0x01, 0x01, 0x03, 0x03,
  0x03, 0x03, 0x03, 0x03, 0x03, 0x03, 0x03, 0x03, 0x03, 0x03,
  0x03, 0x03, 0x03, 0x03, 0x03, 0x03, 0x03, 0x03, 0x03, 0x03,
  0x03, 0x03, 0x03, 0x03, 0x03, 0x03, 0x03, 0x03, 0x03, 0x02,
  0x03, 0x02, 0x03, 0x03, 0x01, 0x03, 0x03, 0x03, 0x03, 0x03,
  0x03, 0x03, 0x03, 0x01, 0x03, 0x03, 0x01, 0x03, 0x03, 0x03,
  0x03, 0x03, 0x03, 0x03, 0x03, 0x03, 0x03, 0x03, 0x03, 0x03,
  0x03, 0x03, 0x01, 0x03, 0x04, 0x03,

  // font data
  0x00, 0x00, // 32
  0xBC, // 33
  0x0C, 0x00, 0x0C, // 34
  0xFC, 0x84, 0xFC, // 35
  0x10, 0xAC, 0x40, // 36
  0x28, 0x20, 0x90, // 37
  0xFC, 0x84, 0xFC, // 38
  0x0C, // 39
  0x84, 0x78, // 40
  0x78, 0x84, // 41
  0x14, 0x08, 0x14, // 42
  0x20, 0x70, 0x20, // 43
  0xC0, // 44
  0x20, 0x20, 0x20, // 45
  0x80, // 46
  0xC0, 0x30, 0x0C, // 47
  0x7C, 0x84, 0xF8, // 48
  0x04, 0xFC, // 49
  0xC8, 0xA4, 0x98, // 50
  0x44, 0x94, 0x6C, // 51
  0x38, 0x20, 0xFC, // 52
  0x5C, 0x94, 0x64, // 53
  0x78, 0x94, 0x60, // 54
  0xC4, 0x34, 0x0C, // 55
  0x68, 0x94, 0x68, // 56
  0x18, 0xA4, 0x78, // 57
  0x48, // 58
  0xC8, // 59
  0x20, 0x50, 0x88, // 60
  0x50, 0x50, 0x50, // 61
  0x88, 0x50, 0x20, // 62
  0x08, 0xA4, 0x18, // 63
  0xFC, 0x84, 0xFC, // 64
  0xFC, 0x24, 0xF8, // 65
  0xFC, 0x94, 0x68, // 66
  0x78, 0x84, 0x84, // 67
  0xFC, 0x84, 0x78, // 68
  0xFC, 0x94, 0x84, // 69
  0xFC, 0x24, 0x04, // 70
  0x78, 0x84, 0xE4, // 71
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
};
static const uint8_t FontNumbers3x6v1[] PROGMEM = {
  0x04, 0x41, // size
  0x03, // width
  0x06, // height
  0x30, // first char
  0x0A, // char count

  // char widths
  0x03, 0x03, 0x03, 0x03, 0x03, 0x03, 0x03, 0x03, 0x03, 0x03,

  // font data
  0xFC, 0x84, 0xFC, // 48
  0x88, 0xFC, 0x80, // 49
  0xE4, 0xA4, 0xBC, // 50
  0x94, 0x94, 0xFC, // 51
  0x3C, 0x20, 0xF0, // 52
  0x9C, 0x94, 0xF4, // 53
  0xFC, 0xA4, 0xE4, // 54
  0x04, 0x04, 0xFC, // 55
  0xFC, 0x94, 0xFC, // 56
  0x1C, 0x14, 0xFC, // 57
};
static const uint32_t imageGenericGuy1[] PROGMEM = {
  8, //width
  8, //height
  0x000000, 0x000000, 0x754c24, 0x754c24, 0x754c24, 0x754c24, 0x000000, 0x000000,
  0x000000, 0x754c24, 0xffc794, 0xffc794, 0xffc794, 0xffc794, 0x000000, 0x000000,
  0x000000, 0x754c24, 0xffc794, 0x2023ff, 0xffc794, 0x2023ff, 0x000000, 0x000000,
  0x000000, 0x754c24, 0xffc794, 0xffc794, 0xffc794, 0xffc794, 0x000000, 0x000000,
  0x000000, 0xf7941d, 0xffc794, 0xffc794, 0xffc794, 0xf7941d, 0x000000, 0x000000,
  0xffc794, 0x000000, 0xf7941d, 0xf7941d, 0xf7941d, 0x000000, 0xffc794, 0x000000,
  0x000000, 0x000000, 0x252525, 0x252525, 0x252525, 0x000000, 0x000000, 0x000000,
  0x000000, 0x000000, 0x363636, 0x000000, 0x363636, 0x000000, 0x000000, 0x000000
};
static const uint32_t imageGenericGuy2[] PROGMEM = {
  8, //width
  8, //height
  0x000000, 0x000000, 0x000000, 0x000000, 0x000000, 0x000000, 0x000000, 0x000000,
  0x000000, 0x000000, 0x754c24, 0x754c24, 0x754c24, 0x754c24, 0x000000, 0x000000,
  0x000000, 0x754c24, 0xffc794, 0xffc794, 0xffc794, 0xffc794, 0x000000, 0x000000,
  0x000000, 0x754c24, 0xffc794, 0x373aff, 0xffc794, 0x373aff, 0x000000, 0x000000,
  0x000000, 0x754c24, 0xffc794, 0xffc794, 0xffc794, 0xffc794, 0x000000, 0x000000,
  0xffc794, 0xf7941d, 0xffc794, 0xffc794, 0xffc794, 0xf7941d, 0xffc794, 0x000000,
  0x000000, 0x000000, 0xf7941d, 0xf7941d, 0xf7941d, 0x000000, 0x000000, 0x000000,
  0x000000, 0x000000, 0x363636, 0x000000, 0x363636, 0x000000, 0x000000, 0x000000
};
static const uint32_t imageEuclidOffset[] PROGMEM = {
  8, //width
  4, //height
  0xff0000, 0xff0000, 0xff0000, 0x000000, 0xff0000, 0xff0000, 0xff0000, 0x000000,
  0xff0000, 0x000000, 0xff0000, 0x000000, 0xff0000, 0x000000, 0x000000, 0x000000,
  0xff0000, 0x000000, 0xff0000, 0x000000, 0xff0000, 0xff0000, 0x000000, 0x000000,
  0xff0000, 0xff0000, 0xff0000, 0x000000, 0xff0000, 0x000000, 0x000000, 0x000000
};
static const uint32_t imageEuclidHits[] PROGMEM = {
  8, //width
  4, //height
  0xff00ff, 0x000000, 0xff00ff, 0x000000, 0xff00ff, 0xff00ff, 0xff00ff, 0xff00ff,
  0xff00ff, 0x000000, 0xff00ff, 0x000000, 0xff00ff, 0x000000, 0xff00ff, 0x000000,
  0xff00ff, 0xff00ff, 0xff00ff, 0x000000, 0xff00ff, 0x000000, 0xff00ff, 0x000000,
  0xff00ff, 0x000000, 0xff00ff, 0x000000, 0xff00ff, 0x000000, 0xff00ff, 0x000000
};
static const uint32_t imageCross5x5[] PROGMEM = {
  5, //width
  5, //height
  0xff0000, 0x00002b, 0x00002b, 0x00002b, 0xff0000,
  0x00002b, 0xff0000, 0x00002b, 0xff0000, 0x00002b,
  0x00002b, 0x00002b, 0xff0000, 0x00002b, 0x00002b,
  0x00002b, 0xff0000, 0x00002b, 0xff0000, 0x00002b,
  0xff0000, 0x00002b, 0x00002b, 0x00002b, 0xff0000
};
static const uint32_t imageChannelSelectionPage[] PROGMEM = {
  7, //width
  8, //height
  0xff95f7, 0xff95f7, 0xff95f7, 0x000000, 0x86c7ff, 0x000000, 0x86c7ff,
  0xff95f7, 0x000000, 0x000000, 0x000000, 0x86c7ff, 0x000000, 0x86c7ff,
  0xff95f7, 0x000000, 0x000000, 0x000000, 0x86c7ff, 0x86c7ff, 0x86c7ff,
  0xff95f7, 0xff95f7, 0xff95f7, 0x000000, 0x86c7ff, 0x000000, 0x86c7ff,
  0x000000, 0x86ff98, 0x000000, 0x000000, 0xffde89, 0xffde89, 0x000000,
  0x86ff98, 0x000000, 0x86ff98, 0x000000, 0xffde89, 0x000000, 0xffde89,
  0x86ff98, 0x86ff98, 0x86ff98, 0x000000, 0xffde89, 0x000000, 0xffde89,
  0x86ff98, 0x000000, 0x86ff98, 0x000000, 0xffde89, 0x000000, 0xffde89
};
static const uint32_t imageSymbolMultiply[] PROGMEM = {
  3, //width
  3, //height
  0x37ff55, 0x000000, 0x37ff55, 
  0x000000, 0x37ff55, 0x000000, 
  0x37ff55, 0x000000, 0x37ff55
};
static const uint32_t imageSymbolDivide[] PROGMEM = {
  3, //width
  4, //height
  0x000000, 0x000000, 0x37ff55, 
  0x000000, 0x37ff55, 0x000000, 
  0x000000, 0x37ff55, 0x000000, 
  0x37ff55, 0x000000, 0x000000
};
static const uint32_t imageGateTrigger[] PROGMEM = {
  6, //width
  6, //height
  0x00c800, 0x00c800, 0x00c800, 0x0000c8, 0x0000c8, 0x000000, 
  0x000000, 0x00c800, 0x0000c8, 0x000000, 0x000000, 0x0000c8, 
  0x000000, 0x00c800, 0x0000c8, 0x000000, 0x000000, 0x000000, 
  0x000000, 0x00c800, 0x0000c8, 0x000000, 0x0000c8, 0x0000c8, 
  0x000000, 0x00c800, 0x0000c8, 0x000000, 0x000000, 0x0000c8, 
  0x000000, 0x00c800, 0x000000, 0x0000c8, 0x0000c8, 0x000000, 
};
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
void loop() {
  #if (SPEED_DEBUG != 0)
  testMeasuringPMill = micros();
  #endif
  if (counter > 63) counter = 0; //counter reset
  comm(counter - ((counter / 8) * 8));
  col(counter / 8);
  clockGeneration(clockRunning, globalInternalBPM, clockMultiplier);
  buttonRead(counter);
  controlButtons();
  counter++;
  gate2Trigger();
  clockResetJacks();
  modeSaving();
  buttonUI(displayButtonMode);
  #if (SPEED_DEBUG == 2)
  Serial.println(micros() - testMeasuringPMill);
  #endif
  showLed(brightnessAdj, 30);
  #if (SPEED_DEBUG == 1)
  Serial.println(micros() - testMeasuringPMill);
  #endif
}

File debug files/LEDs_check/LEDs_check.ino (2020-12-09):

#include <FastLED.h>

//This firmware just sets all LEDs to the same colors (red, gree, blue, yellow, magenta, white, black) 

#define BRIGHTNESS 50 //the overall brightness of all LEDs, the value can go from 0 to 255 but your leds might turn red and die off if you set it to over 100 (its not permanent, just remove power frojm the module to reset the volatge regulator current fuse)
#define SPEED 1000 //the time each color stays on (in millisecconds)

CRGB leds[72];

void setup() { 
  FastLED.addLeds<WS2812B, 9, RGB>(leds, 72);
  FastLED.setBrightness(BRIGHTNESS);
}

void loop() {
  for (uint8_t i = 0; i < 72; i++) leds[i] = 0xff0000;
  FastLED.show();
  delay(SPEED);
  for (uint8_t i = 0; i < 72; i++) leds[i] = 0x00ff00;
  FastLED.show();
  delay(SPEED);
  for (uint8_t i = 0; i < 72; i++) leds[i] = 0x0000ff;
  FastLED.show();
  delay(SPEED);
  for (uint8_t i = 0; i < 72; i++) leds[i] = 0xffff00;
  FastLED.show();
  delay(SPEED);
  for (uint8_t i = 0; i < 72; i++) leds[i] = 0x00ffff;
  FastLED.show();
  delay(SPEED);
  for (uint8_t i = 0; i < 72; i++) leds[i] = 0xffffff;
  FastLED.show();
  delay(SPEED);
  for (uint8_t i = 0; i < 72; i++) leds[i] = 0x000000;
  FastLED.show();
  delay(SPEED);
}

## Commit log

2018-12-15 The pcb and schematic
    [copper_bottom.gbr, copper_top.gbr, drills.xln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]
2019-09-08 pcb 2.0 finished
    [circadian rev2.0.brd, circadian rev2.0.sch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]
2019-09-22 added BOM
    [circad 2.0 bom.xlsx]
2019-09-22 updated to the new pcb
2020-02-18 BOM is fixed, Im sorry for that scam link.
    Hopefully nobody bought that arduino pro mini.
    [circad 2.0 bom.xlsx]
2020-07-07 added debug files for easier fixing
    [LEDs_check.ino]
2020-07-07 Added PCB and Schematic images
2021-09-23 Fixed the BOM
    [circad 2.0 bom.xlsx]
2023-11-24 fixed mistakes on the pcb
    There are no pictures, no BOM and no additional files, this is really just a hotfix
    [circadian rev2.1.brd, circadian rev2.1.sch]
2023-11-27 Added and fixed a BOM for 2.1
    [circad 2.1 bom.xlsx]
2023-12-16 Added a comment fo fix confusion
    [circad 2.1 bom.xlsx]
2023-12-16 Fixed wrong LED type causing confusion
    [circadian rev2.1.brd, circadian rev2.1.sch]

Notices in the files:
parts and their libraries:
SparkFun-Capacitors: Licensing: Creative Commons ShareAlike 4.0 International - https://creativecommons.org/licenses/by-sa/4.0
